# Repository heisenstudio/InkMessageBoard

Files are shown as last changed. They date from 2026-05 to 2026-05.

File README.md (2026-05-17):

# InkMessageBoard 墨水屏留言板

中文 | [English](README.en.md)

> 这是一个个人学习和交流用的开源原型项目，欢迎参考、复现和继续改进。它不是成熟商业产品，不保证商用稳定性，也不建议未经验证直接量产。

InkMessageBoard 是一个基于 **ESP32-S3、墨水屏、MQTT 和 Android App** 的留言板原型项目。核心流程是：Android App 输入留言，通过 MQTT 发布消息；ESP32-S3 连接 Wi-Fi 和 MQTT Broker，收到留言后刷新墨水屏；设备也可以上报在线状态、电量、RSSI、固件版本和留言处理状态。

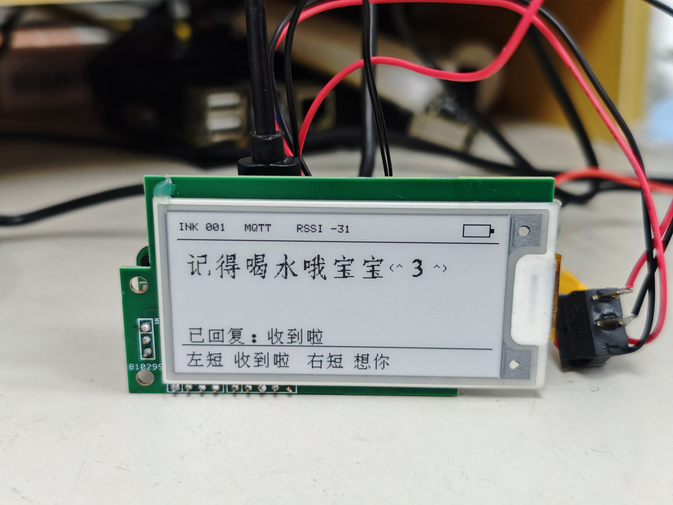
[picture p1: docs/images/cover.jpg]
设备实物


## 项目图片

| 设备正面 | 设备侧面 |
| --- | --- |
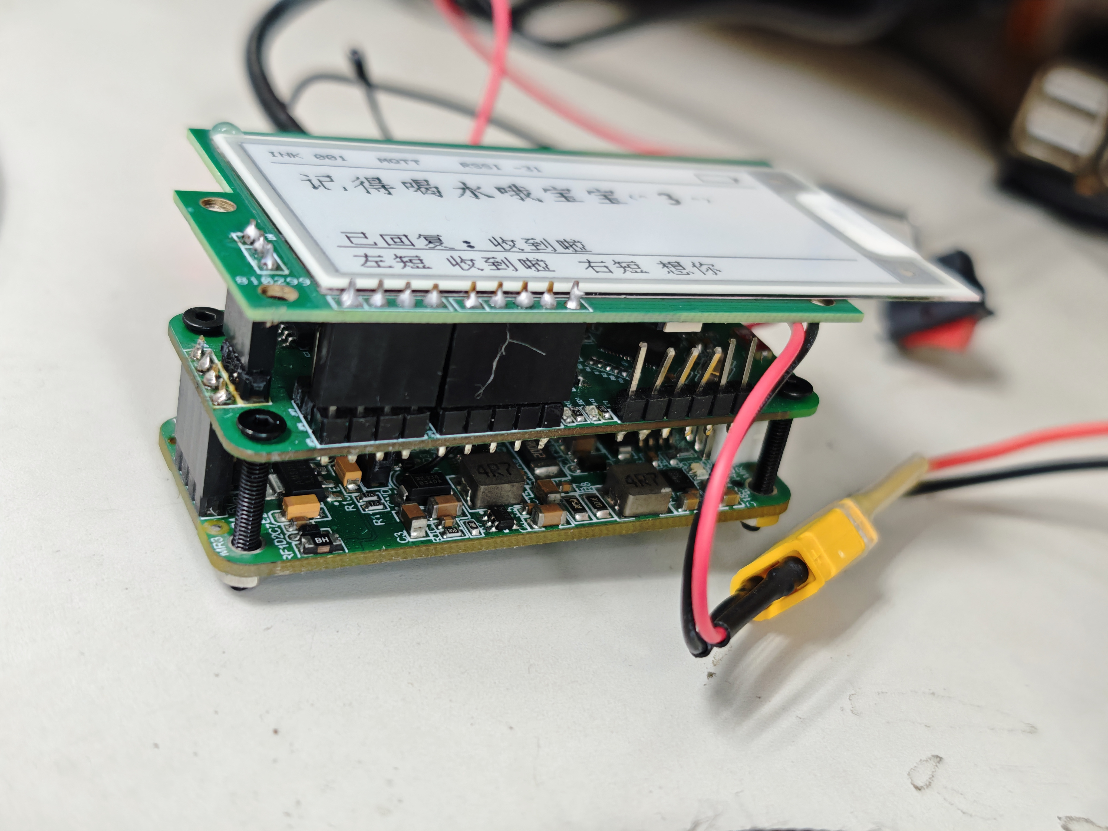
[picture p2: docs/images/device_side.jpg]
设备侧面
| 设备正面 |  |

| App 界面 | 系统架构 |
| --- | --- |
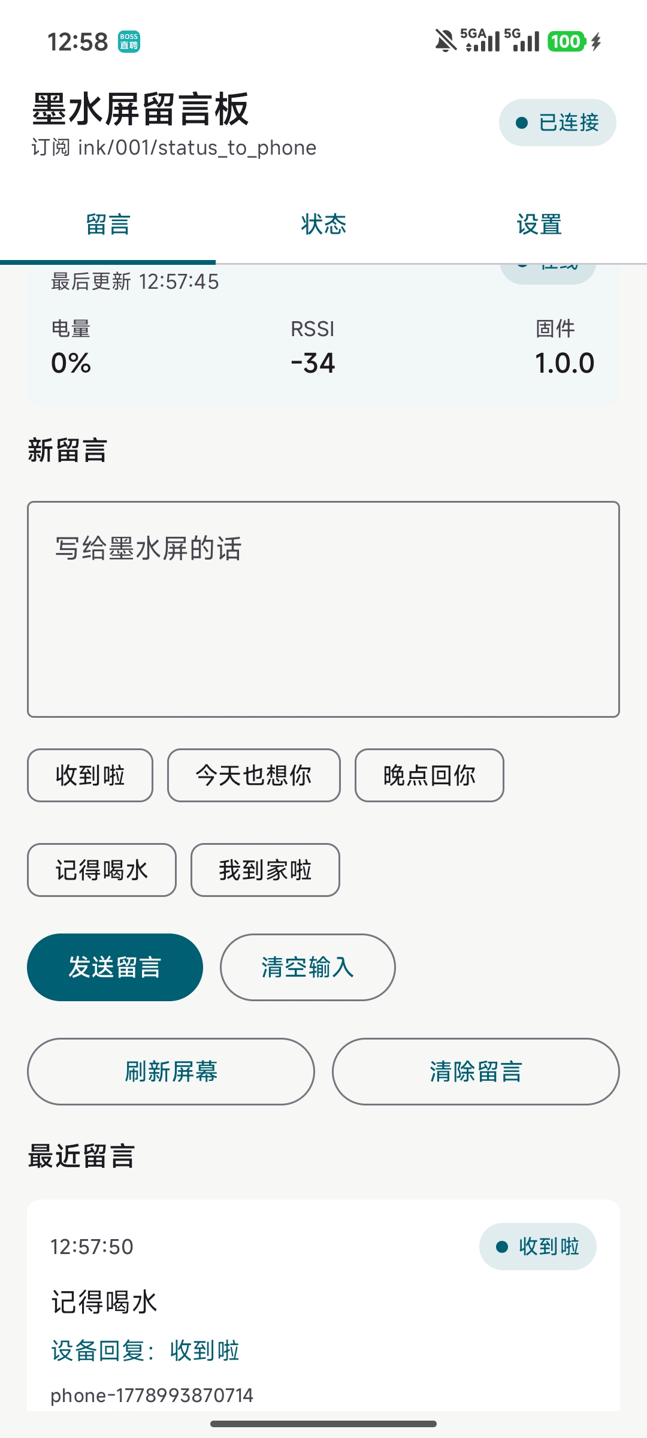
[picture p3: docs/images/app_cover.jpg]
App 界面
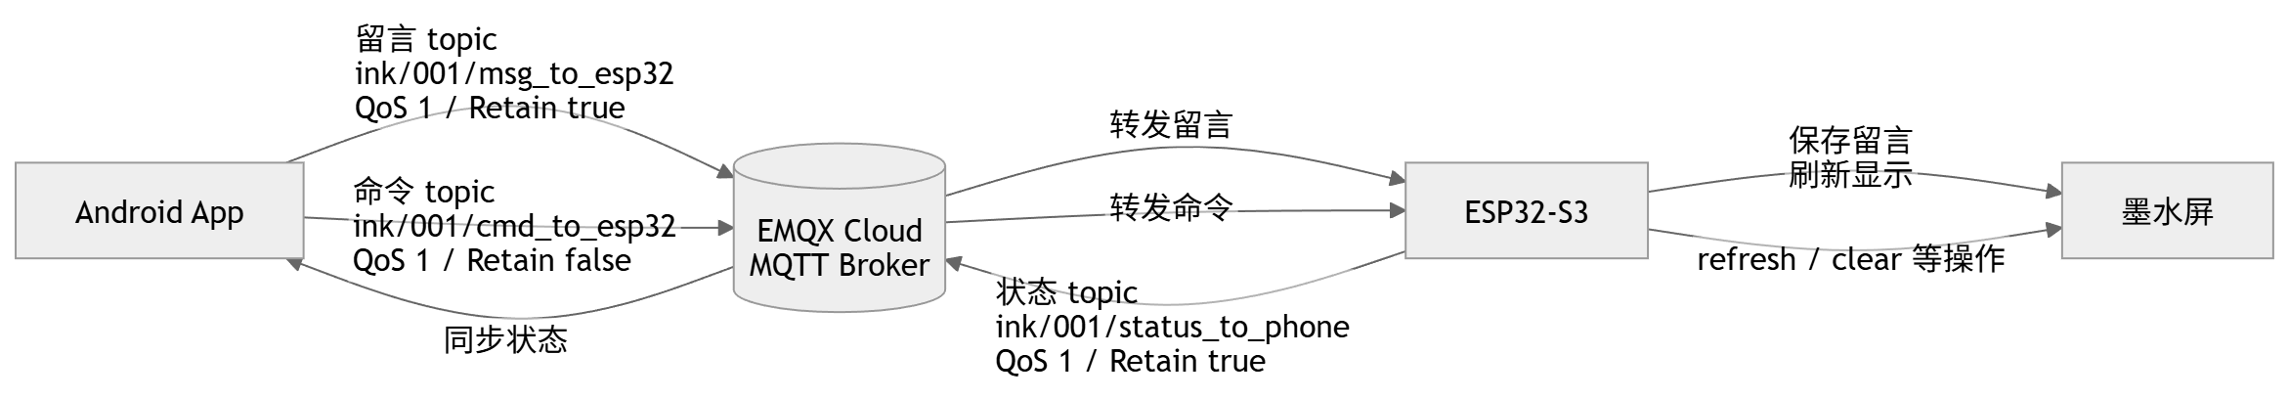
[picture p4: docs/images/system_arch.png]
系统架构
|  |  |

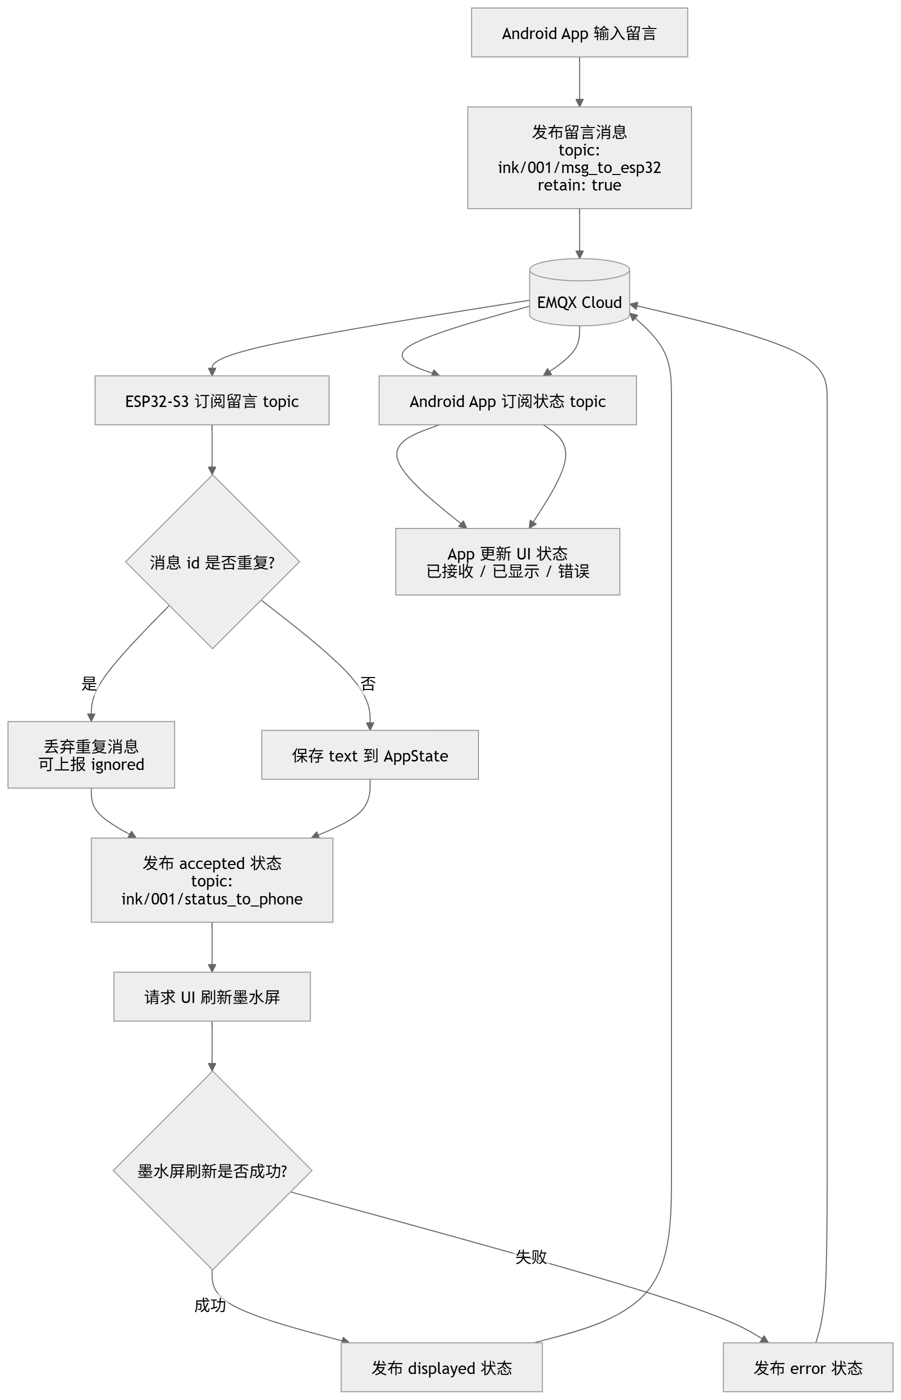
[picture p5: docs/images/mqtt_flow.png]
留言发送与状态回执流程


## 已跑通的流程

1. Android App 输入留言。
2. App 通过 MQTT 发布消息。
3. ESP32-S3 连接 Wi-Fi 和 MQTT Broker。
4. ESP32-S3 订阅留言 Topic 和命令 Topic。
5. ESP32-S3 收到留言后刷新墨水屏。
6. 设备可以通过触摸按键回传简单状态。
7. App 可以看到设备上报的在线、电量、RSSI、固件版本等信息。

MQTT 测试时使用过 EMQX Cloud。仓库里不包含真实 Broker 地址、用户名和密码，复现时请填写自己的测试账号。

## 项目定位

这个仓库主要是学习记录和交流资料，不是成熟产品。它适合用来学习：

- ESP32-S3 + Arduino/PlatformIO 工程组织
- Wi-Fi、MQTT、TLS 连接和重连
- 墨水屏刷新和中文点阵字体显示
- Android Compose 简单界面
- Android 与嵌入式设备之间的 MQTT 交互
- 原理图、PCB、Gerber、BOM 等开源硬件资料整理

目前仍然不完善：

- 没有做成稳定商品
- 没有完整安全设计
- 没有完整生产测试流程
- Android 和固件代码还有继续整理空间
- 文档中的参数、调试经验和复现细节仍可继续补充

## 仓库结构

```text
InkMessageBoard/
├── android/              # Android App 工程
├── firmware/esp32/       # ESP32-S3 PlatformIO 固件工程
├── hardware/             # 三块板子的源工程、原理图、PCB 图、Gerber、BOM
├── docs/                 # 构建、协议、软硬件说明
└── media/                # 视频脚本和演示素材
```

## 文档入口

- [软件介绍](docs/software_overview.md)
- [硬件介绍](docs/hardware_overview.md)
- [MQTT 协议](docs/mqtt_protocol.md)
- [ESP32 固件编译](docs/build_firmware.md)
- [Android App 编译](docs/build_android.md)
- [硬件连接](docs/hardware_connection.md)
- [已知问题](docs/known_issues.md)

## 开源内容

当前仓库包含：

- ESP32-S3 固件源码和 PlatformIO 配置
- Android App 源码和 Gradle 配置
- 三块板子的硬件源工程
- 原理图 PDF
- PCB 正反面图片
- Gerber 压缩包
- BOM 和贴片坐标文件
- 设备照片、流程图和 App 展示图

## 隐私和凭据

公开发布前已经处理：

- 删除 Android `local.properties`
- 删除 Android/ESP32 构建缓存
- 删除固件工程里嵌套的 `.git`
- 移除真实 EMQX Cloud Host、用户名和密码
- 示例配置使用占位符

你自己 fork 或二次发布前，也请再检查一次 Wi-Fi、MQTT、截图、串口日志和图片背景里是否有私人信息。

## 许可证

当前仓库的软件代码、文档、图片资料和硬件设计文件默认都使用 MIT License，见 [LICENSE](LICENSE)。

硬件部分同样按 MIT License 开放，方便大家学习、修改、制造和继续完善。打板和使用前请自行核对原理图、PCB、BOM、Gerber 和装配方式。

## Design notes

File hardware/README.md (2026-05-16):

# Hardware

这里放的是 InkMessageBoard 的硬件资料。当前是学习原型资料，不是成熟量产包。

硬件设计文件默认使用 MIT License，和仓库根目录 [LICENSE](../LICENSE) 保持一致。你可以学习、修改、制造和分发，但打板和使用前需要自行核对设计文件。

## 板子

| 板子 | 源工程 | 说明 |
| --- | --- | --- |
| ESP32-S3 主控板 | `source/altium/esp32_s3_board/` | AD 工程 |
| 电源板 | `source/altium/power_board/` | AD 工程 |
| 2.66 寸墨水屏板 | `source/lceda/ink_board/` | 嘉立创 EDA 工程 |

## 目录

```text
hardware/
├── source/       # 可编辑源工程
├── schematic/    # 原理图 PDF
├── pcb/          # PCB 正反面图片
├── gerber/       # Gerber 压缩包
├── bom/          # BOM 表
└── production/   # 贴片坐标和装配说明
```

## 开源硬件说明

硬件开源不只是放几张图。这个目录里保留了可编辑源工程，也另外导出了原理图、PCB 图片、Gerber、BOM 和贴片坐标，方便别人学习、检查或继续修改。

发布或打板前建议再做一次人工核对：

- 原理图是否对应当前固件引脚
- PCB 是否是实际测试过的版本
- BOM 封装和值是否正确
- Gerber 和贴片坐标是否来自同一版工程
- 电源输入、屏幕排线方向、触摸按键是否和实物一致

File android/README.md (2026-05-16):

# Android App

这里是 InkMessageBoard 的 Android App 工程。

这个 App 是学习原型，不是完整产品。它主要用来测试 Android 端通过 MQTT 给 ESP32-S3 发送留言，并查看设备回传状态。

## 功能

- 填写 MQTT host、端口、用户名、密码和设备 ID
- 连接 MQTT Broker
- 发送留言到 ESP32-S3
- 发送刷新/清除命令
- 显示设备状态 topic 和事件日志

## 构建

见 [../docs/build_android.md](../docs/build_android.md)。

## 隐私

仓库里不应该包含真实 MQTT 密码、签名文件或 `local.properties`。

当前默认 MQTT 配置是占位符。请在本地填写自己的 EMQX Cloud 或其他 MQTT Broker 信息。

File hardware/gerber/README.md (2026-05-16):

# Gerber

这里放 PCB 生产文件压缩包。

当前包括：

- `esp32_s3_board_gerber.zip`
- `power_board_gerber.zip`

`ink_board` 当前只整理了嘉立创 EDA 源工程和原理图 PDF，如需打板，请从源工程重新导出对应生产文件。

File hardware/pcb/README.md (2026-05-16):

# PCB Images

这里放 PCB 正反面预览图。

当前包括：

- `esp32_s3_board_front.png`
- `esp32_s3_board_back.png`
- `power_board_front.png`
- `power_board_back.png`
- `ink_board_front.png`
- `ink_board_back.png`

图片方便在 GitHub 上快速查看，真正可修改的源工程在 `hardware/source/`。

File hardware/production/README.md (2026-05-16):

# Production Files

这里放生产和装配相关文件。

当前包括：

- `esp32_s3_board_PickAndPlace.csv`
- `esp32_s3_board_PickAndPlace.txt`
- `power_board_PickAndPlace.csv`
- `assembly_notes.md`

这些文件适合学习和打样参考。正式下单前请重新从源工程导出并核对。

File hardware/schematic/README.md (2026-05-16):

# Schematic

这里放原理图导出文件。

当前包括：

- `esp32_s3_board.pdf`
- `power_board.pdf`
- `ink_board.pdf`

发布前建议继续核对：这些 PDF 是否和 `hardware/source/` 中的源工程、`hardware/gerber/` 中的生产文件对应同一版本。

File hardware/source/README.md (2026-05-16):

# Hardware Source Files

这里放可编辑的硬件源工程。

## 当前内容

```text
source/
├── altium/
│   ├── esp32_s3_board/
│   └── power_board/
└── lceda/
    └── ink_board/
```

`altium/` 下面是 AD 工程，`lceda/` 下面是嘉立创 EDA 工程。

这些源文件比导出的图片/Gerber 更重要，因为别人可以基于它们学习、修改、重新导出生产文件。

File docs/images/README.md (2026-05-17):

# Image Assets

这里放 README 和文档会引用的图片。

当前包括：

| File | Content |
| --- | --- |
| `cover.jpg` | 项目封面图 |
| `device_front.jpg` | 设备实物正面 |
| `device_side.jpg` | 设备侧面 |
| `app_cover.jpg` | Android App 展示图 |
| `pcb_front.png` | ESP32-S3 主控板正面图 |
| `pcb_back.png` | ESP32-S3 主控板背面图 |
| `system_arch.png` | 三条 Topic 总体数据流 |
| `mqtt_flow.png` | 留言发送与状态回执流程 |

没有放入显示真实 EMQX Cloud host 的状态页截图。公开截图前请检查是否包含 broker 地址、账号、密码、手机号、定位等私人信息。

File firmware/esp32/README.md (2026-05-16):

# ESP32 Firmware

This is the ESP32-S3 firmware for the InkMessageBoard prototype.

The firmware connects to Wi-Fi, connects to an MQTT broker, receives messages from the Android app, and refreshes the e-paper display. It is shared as a learning/reference project, not as a polished production firmware.

## Main Features

- Wi-Fi connection and retry
- MQTT over TLS, tested with free EMQX Cloud
- Message, command, and status topics
- E-paper UI pages for boot, offline, idle, message, and reply state
- Basic battery/status reporting
- GB2312 font data for Chinese text rendering

## Build

Install PlatformIO, then build from this directory:

```bash
pio run
```

Flash:

```bash
pio run --target upload
```

Upload filesystem data if needed:

```bash
pio run --target uploadfs
```

## Configuration

Edit `src/config/AppConfig.h` before building.

The values in that file are placeholders. Replace them with your own Wi-Fi and MQTT information. Do not publish real Wi-Fi passwords, MQTT passwords, or private broker addresses.

## Dependencies

Third-party Arduino libraries are declared in `platformio.ini` through `lib_deps`. Build caches and downloaded libraries are intentionally not committed.

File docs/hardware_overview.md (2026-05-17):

# 硬件介绍

这个项目的硬件部分目前包含三块板子的资料。它们都是学习和原型验证用途，不建议直接当成成熟量产资料使用。

硬件设计文件同样使用 MIT License 开放。你可以学习、修改、制造和分发，但实际打板、装配、供电和使用风险需要自行确认。

## 板子列表

| 板子 | 工程类型 | 说明 |
| --- | --- | --- |
| ESP32-S3 主控板 | Altium Designer | 主控、Wi-Fi/MQTT、墨水屏控制、触摸输入等 |
| 电源板 | Altium Designer | 供电相关电路 |
| 2.66 寸墨水屏板 | 嘉立创 EDA | 墨水屏连接/转接相关电路 |

## 开源资料位置

```text
hardware/
├── source/
│   ├── altium/
│   │   ├── esp32_s3_board/
│   │   └── power_board/
│   └── lceda/
│       └── ink_board/
├── schematic/
├── pcb/
├── gerber/
├── bom/
└── production/
```

## 已整理的文件

- AD 源工程：`hardware/source/altium/`
- 嘉立创 EDA 工程：`hardware/source/lceda/`
- 原理图 PDF：`hardware/schematic/`
- PCB 正反面图：`hardware/pcb/`
- Gerber 压缩包：`hardware/gerber/`
- BOM：`hardware/bom/`
- 贴片坐标：`hardware/production/`

## 实物和 PCB 图片

设备正面

设备侧面

## PCB 图片

### ESP32-S3 主控板

| 正面 | 背面 |
| --- | --- |
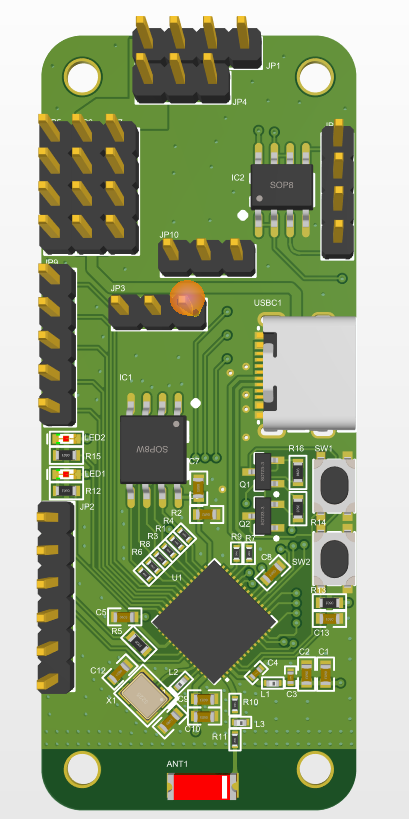
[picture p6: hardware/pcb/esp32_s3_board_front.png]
ESP32-S3 主控板正面
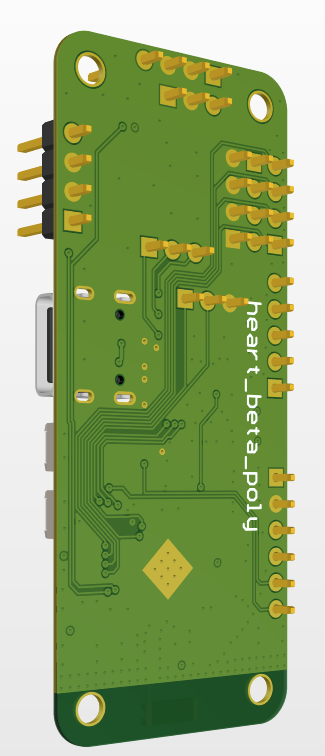
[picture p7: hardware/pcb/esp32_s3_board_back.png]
ESP32-S3 主控板背面
|  |  |

### 电源板

| 正面 | 背面 |
| --- | --- |
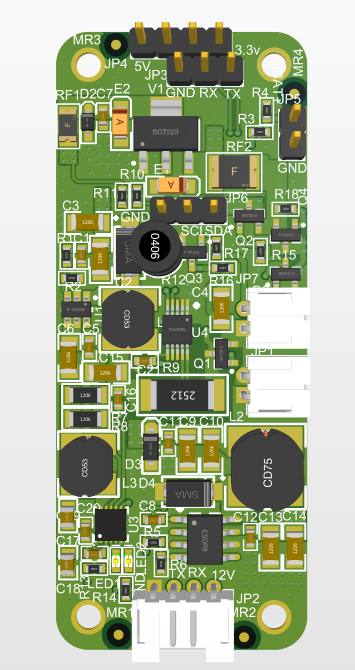
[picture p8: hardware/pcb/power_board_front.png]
电源板正面
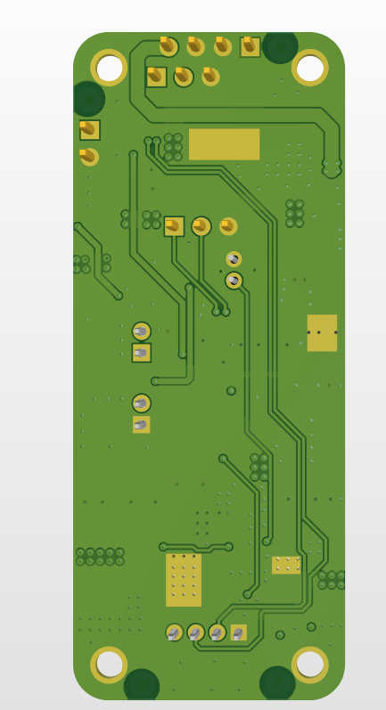
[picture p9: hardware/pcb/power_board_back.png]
电源板背面
|  |  |

### 2.66 寸墨水屏板

| 正面 | 背面 |
| --- | --- |
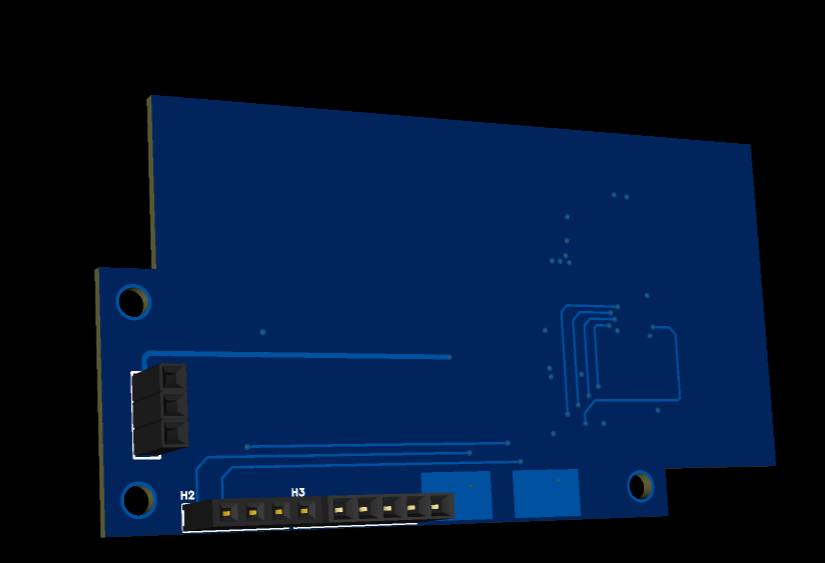
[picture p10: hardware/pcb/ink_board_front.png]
墨水屏板正面
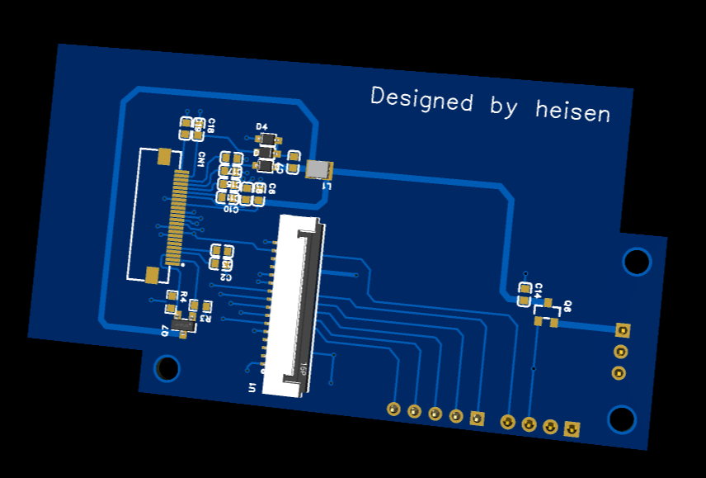
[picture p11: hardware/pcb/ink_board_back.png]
墨水屏板背面
|  |  |

## 注意事项

- 硬件源文件是开源硬件最重要的部分，图片和 Gerber 不能完全替代源工程。
- 发布或打板前，请重新检查原理图、封装、BOM 和 Gerber 是否对应同一个版本。
- 如果你要基于这个项目改板，建议先从原理图和实际焊接照片一起核对。
- 电源、电池、充电、墨水屏排线方向这些地方需要特别小心。

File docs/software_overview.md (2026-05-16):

# 软件介绍

这个项目的软件部分分成两块：

- ESP32-S3 固件：负责联网、接收 MQTT 消息、驱动墨水屏、上报状态。
- Android App：负责输入留言、连接 MQTT Broker、发布消息和命令、显示设备状态。

整体上它是一个学习用的 IoT 原型，不是完整产品级架构。代码能作为参考，但仍然有很多地方可以继续整理。

## 通信流程

三条 Topic 总体数据流

留言发送与状态回执流程

```text
Android App
   |
   | MQTT over TLS
   v
EMQX Cloud / MQTT Broker
   |
   | MQTT over TLS
   v
ESP32-S3
   |
   v
E-paper display
```

测试时使用过免费的 EMQX Cloud。仓库里不包含真实 host、用户名和密码，请在本地配置自己的 MQTT 信息。

## ESP32-S3 固件

固件位置：

```text
firmware/esp32/
```

主要模块：

| 模块 | 作用 |
| --- | --- |
| `main.cpp` | 主循环、消息解析、屏幕刷新调度 |
| `service/WifiService.*` | Wi-Fi 连接 |
| `service/MqttService.*` | MQTT TLS 连接、订阅、发布 |
| `service/KeyService.*` | 左右触摸按键 |
| `service/BatteryService.*` | 电量采样和状态 |
| `bsp/BspEpaper.*` | 墨水屏底层封装 |
| `bsp/BspBattery.*` | INA226 电量检测 |
| `data/fonts/` | HZK 点阵字体和 Unicode/GB2312 映射 |

固件当前使用 PlatformIO + Arduino framework。第三方库通过 `platformio.ini` 的 `lib_deps` 下载，不提交 `.pio` 缓存。

## Android App

App 位置：

```text
android/
```

主要模块：

| 模块 | 作用 |
| --- | --- |
| `MainActivity.kt` | Compose 页面和交互 |
| `GuestbookController.kt` | App 状态、MQTT 配置、消息发送 |
| `mqtt/SimpleMqttClient.kt` | 一个简单的 MQTT over TLS 客户端实现 |

App 目前比较直接：启动后使用配置连接 MQTT，留言页发布消息，状态页显示 topic 和设备回传事件，设置页可以修改 broker、账号、设备 ID 等信息。

## 还可以完善的方向

- 把 MQTT 配置做成更清晰的首次启动引导。
- 增加连接失败原因提示。
- App 端可以增加本地配置导入/导出。
- 固件可以增加更稳健的断线重连策略。
- 固件中文字符串和字体资源还可以继续整理。
- 可以把系统架构图和 MQTT 流程图补成图片。

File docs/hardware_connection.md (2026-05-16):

# Hardware Connection

这里先按当前固件里的引脚定义整理，后续如果硬件版本变化，需要同步检查原理图和代码。

## 主要硬件

| 部分 | 说明 |
| --- | --- |
| MCU | ESP32-S3 |
| 显示 | 2.66 寸黑白墨水屏，固件使用 `GxEPD2_260` |
| 电量检测 | INA226 |
| 输入 | 左右触摸按键 |
| 通信 | Wi-Fi + MQTT over TLS |

## 墨水屏 SPI

| 功能 | ESP32-S3 GPIO | 固件宏 |
| --- | --- | --- |
| SCK | GPIO33 | `BSP_EPAPER_SPI_SCK_PIN` |
| MOSI | GPIO34 | `BSP_EPAPER_SPI_MOSI_PIN` |
| MISO | 未使用 | `BSP_EPAPER_SPI_MISO_PIN = -1` |
| CS | GPIO47 | `BSP_EPAPER_CS_PIN` |
| DC | GPIO48 | `BSP_EPAPER_DC_PIN` |
| RST | GPIO35 | `BSP_EPAPER_RST_PIN` |
| BUSY | GPIO8 | `BSP_EPAPER_BUSY_PIN` |
| Power Enable | GPIO9 | `BSP_EPAPER_POWER_EN_PIN` |

## INA226 电量检测

| 功能 | ESP32-S3 GPIO | 固件宏 |
| --- | --- | --- |
| SDA | GPIO12 | `BSP_BATTERY_SDA_PIN` |
| SCL | GPIO13 | `BSP_BATTERY_SCL_PIN` |
| I2C 地址 | `0x40` | `BSP_BATTERY_I2C_ADDRESS` |

## 触摸按键

| 功能 | ESP32-S3 GPIO | 固件宏 |
| --- | --- | --- |
| 左触摸 | GPIO11 | `KEYSERVICE_LEFT_TOUCH_PIN` |
| 右触摸 | GPIO10 | `KEYSERVICE_RIGHT_TOUCH_PIN` |

## 注意

- 这些引脚来自当前固件，开源发布前最好再和 AD/嘉立创 EDA 原理图逐项核对。
- 墨水屏排线方向、电源使能、电池检测电阻值都建议在装配说明里继续补图。
- 如果你改板，请同步改 `firmware/esp32/src/bsp/` 和 `firmware/esp32/src/service/` 里的默认宏。

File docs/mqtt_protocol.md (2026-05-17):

# MQTT Protocol

这个项目目前使用 MQTT 做 App 和 ESP32-S3 之间的通信。测试时使用过免费的 EMQX Cloud，端口为 `8883`，连接走 TLS。

仓库不提供真实 broker 地址、用户名和密码。请在本地填自己的配置。

## Topics

默认设备 ID 是 `001`。

| 方向 | Topic | 作用 |
| --- | --- | --- |
| App -> ESP32 | `ink/001/msg_to_esp32` | 发送留言 |
| App -> ESP32 | `ink/001/cmd_to_esp32` | 发送控制命令 |
| ESP32 -> App | `ink/001/status_to_phone` | 上报设备状态、留言状态和按键回复 |

## 留言消息

App 发布到 `ink/001/msg_to_esp32`：

```json
{
  "id": "phone-1778844537408",
  "type": "guestbook",
  "text": "请查看设备状态",
  "ts": 1778844537
}
```

字段：

| 字段 | 类型 | 必填 | 说明 |
| --- | --- | --- | --- |
| `id` | string | 是 | 消息 ID，用于去重和状态回传 |
| `type` | string | 否 | 当前 App 使用 `guestbook` |
| `text` | string | 是 | 显示到墨水屏上的文字 |
| `ts` | number | 否 | App 侧生成的 Unix 时间戳 |

## 控制命令

App 发布到 `ink/001/cmd_to_esp32`：

```json
{
  "id": "cmd-1778844537408",
  "cmd": "refresh"
}
```

当前命令：

| 命令 | 说明 |
| --- | --- |
| `refresh` | 强制刷新屏幕 |
| `clear` | 清除当前留言并刷新 |

## 设备状态

ESP32 发布到 `ink/001/status_to_phone`：

```json
{
  "online": true,
  "battery": 80,
  "rssi": -38,
  "fw": "1.0.0"
}
```

## 留言状态回传

ESP32 收到、显示或按键回复后，也发布到 `ink/001/status_to_phone`：

```json
{
  "msg_id": "phone-1778844537408",
  "state": "displayed"
}
```

带回复文本的例子：

```json
{
  "msg_id": "phone-1778844537408",
  "state": "seen",
  "text": "已收到"
}
```

常见 `state`：

| state | 说明 |
| --- | --- |
| `accepted` | ESP32 已接收消息 |
| `displayed` | ESP32 已刷新到墨水屏 |
| `seen` | 左短按回复，表示已收到 |
| `confirm` | 右短按回复，表示需要确认 |
| `later` | 左长按回复，表示稍后处理 |
| `done` | 右长按回复，表示已处理 |

## 注意

- 免费 MQTT Broker 适合学习测试，不建议传隐私内容。
- 真实 host、用户名、密码不要提交到 GitHub。
- 当前固件使用 `setInsecure()`，也就是没有校验证书链，后续可以继续完善 TLS 证书校验。

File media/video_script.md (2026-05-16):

# Demo Video Script

## Title

ESP32 墨水屏 MQTT 留言板原型

## 30-60 Second Flow

1. Show the assembled device.
2. Show the Android app input screen.
3. Enter a short message.
4. Tap send.
5. Show MQTT message being delivered, if you want to include a debug shot.
6. Show the e-paper display refreshing.
7. End with the GitHub repository structure: firmware, android, hardware, docs.

## Key Message

这是一个 ESP32 + 墨水屏 + MQTT + Android App 的留言板原型项目。核心功能已跑通，适合作为嵌入式 IoT 学习和作品集参考。

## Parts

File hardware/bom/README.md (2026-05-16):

# BOM

这里放物料清单。

当前包括：

- `esp32_s3_board_BOM.xlsx`
- `power_board_BOM.xlsx`

这些文件来自工程输出。发布或打样前建议人工核对型号、封装和值。

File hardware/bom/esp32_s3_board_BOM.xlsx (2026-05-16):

Comment | Description | Designator | Footprint | LibRef | Quantity
CrossAir CA-C03 | 2450±50MHz 4.3DBi 50欧 功率3W | ANT1 | crossair ca-co3 | CrossAir CA-C03 | 1
10uf | 贴片电容/MLCC电容 | C1 | C0603_L | C | 1
1uf | 贴片电容/MLCC电容 | C2, C6, C9, C13 | C0603_L | C | 4
100nf | 贴片电容/MLCC电容 | C3, C4 | C0402_L | C | 2
100nf | 贴片电容/MLCC电容 | C5, C7, C8 | C0603_L | C | 3
10nf | 贴片电容/MLCC电容 | C10 | C0603_L | C | 1
24pf | 贴片电容/MLCC电容 C1654 | C11, C12 | C0603_L | C | 2
W25Q64 | SPI Flash C83140 | IC1 | SOP8W_L | W25Q | 1
LM358 | 双路运放 | IC2 | SOP8_N | LM358 | 1
HDR-1X4 | 4P接插件 | JP1, JP5, JP6, JP7, JP8 | HDR2.54-LI-4P | Header 4 | 5
HDR-1X6 | 6P接插件 | JP2 | HDR2.54-LI-6P | Header 6 | 1
HDR-1X3 | 3P接插件 | JP3, JP4, JP10 | HDR2.54-LI-3P | Header 3 | 3
HDR-1X5 | 5P接插件 | JP9 | HDR2.54-LI-5P | Header 5 | 1
2nh | 贴片小功率电感 C18216 | L1 | L0402 | L | 1
24nh | 贴片小功率电感 C74301 | L2 | L0402 | L | 1
3nh | 贴片小功率电感 | L3 | L0402 | L | 1
红色 | 贴片LED | LED1, LED2 | LED0603_R | LED | 2
SS8050 | 高频放大-NPN型 | Q1, Q2 | SOT23-3N | 8050-SMD | 2
0R | 贴片电阻 | R1, R2, R3, R4, R6, R7, R8, R9, R10, R11 | R0402_L | R | 10
499R | 贴片电阻 | R5 | R0603_L | R | 1
470R | 贴片电阻 | R12, R15 | R0603_L | R | 2
10K | 贴片电阻 | R13, R14, R16 | R0603_L | R | 3
3*4*2.5 | 贴片4脚轻触开关 C2690012 | SW1, SW2 | SW-SMD-4.2x3.2_4P | SW SMD-3*4*2.5 | 2
ESP32-S3 | 2.4 GHz Wi-Fi + 低功耗蓝牙 SoC | U1 | QFN56 7x7 | ESP32-S3 | 1
TYPE-C 2.0 -16P | USB2.0_Type-C_16Pin母座 | USBC1 | USB-C-SMD_16P | USB2.0_Type-C_16Pin | 1
40Mhz | 4脚无源晶振(谐振器）C5203551 | X1 | XTAL-3225-4P | XTAL-4P | 1

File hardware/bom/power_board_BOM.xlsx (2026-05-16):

Comment | Description | Designator | Footprint | LibRef | Quantity | jlc_id
100nf | 贴片电容/MLCC电容 | C1, C5, C11, C12, C16, C17, C20, C21 | C0603_L | C | 8
100uf/6.3V | 贴片电容/MLCC电容, 贴片电容/MLCC电容 C15008 | C2, C3, C4, C9, C10, C15 | C1206_L | C | 6 | C15008, [NoParam], C45783
22uf/25V | 贴片电容/MLCC电容, 贴片电容/MLCC电容 C12891 | C6, C13, C14 | C1206_L | C | 3
4.7uf | 贴片电容/MLCC电容 | C7 | C0603_M | C | 1
10nf | 贴片电容/MLCC电容 | C8 | C0603_L | C | 1
22uf/25v | 贴片电容/MLCC电容 | C18, C19 | C0805_L | C | 2 | C45783
B340A-13-F | 肖特基二极管 C85098 | D1, D4 | SMA | B340A-13-F | 2
UDD32C03L01 | TVS通用 C78439 | D2 | SOD-323 | TVS | 1
SMF5.0A | TVS通用 | D3 | SOD-123 | TVS | 1
10uF/10V | 贴片钽电容 C7171 | E1 | C_3216 | CT | 1
22uF/10V | 贴片钽电容 C11366 | E2 | C_3216 | CT | 1
HDR-1X2 | 2P接插件 | JP1, JP7 | PH2.0-W-2P | Header 2 | 2
HDR-1X4 | 4P接插件 | JP2 | PH2.0-W-4P | Header 4 | 1
HDR-1X3 | 3P接插件 | JP3, JP6 | HDR2.54-LI-3P | Header 3 | 2
HDR-1X4 | 4P接插件 | JP4 | HDR2.54-LI-4P | Header 4 | 1
HDR-1X2 | 2P接插件 | JP5 | HDR2.54-LI-2P | Header 2 | 1
4.7uH | CD系列贴片线绕功率电感 | L1, L3 | CD53 | L-SMD | 2 | C177246
15uH | CD系列贴片线绕功率电感 | L2 | CD75 | L-SMD | 1 | C177243
红色 | 贴片LED | LED1 | LED0603_Y | LED | 1
绿色 | 贴片LED | LED2 | LED0603_Y | LED | 1
MARK1.6 | 光学定位点 | MR1, MR2, MR3, MR4 | Mark 1 | MARK | 4
AO3401 | P沟道 30V/4.2A | Q1, Q2, Q4 | SOT23-3N | AO3401 | 3 | C347476
S8050 | NPN三极管 | Q3 | SOT23-3M | BCP68 | 1
AO3400 | N沟道 30V/4.2A | Q5 | SOT23-3N | AO3400 | 1 | C20917
110K | 贴片电阻 | R1 | R0603_L | R | 1
15K | 贴片电阻 | R2 | R0603_L | R | 1
10K/0.1% | 贴片电阻 | R3, R4 | R0603_L | R | 2
10k | 贴片电阻 | R5, R17 | R0603_L | R | 2
3.24k | 贴片电阻 | R6 | R0603_L | R | 1
0.05R | 贴片电阻 | R7 | R1206_L | R | 1 | C127691
0.1R | 贴片电阻 | R8 | R1206_L | R | 1 | C25334
0.002R | 贴片电阻 | R9 | R2512_M | R | 1 | C2994640
4.7K | 贴片电阻 | R10, R11 | R0603_L | R | 2
471K | 热敏电阻 | R12 | PK0406 | RT | 1
1K | 贴片电阻 | R13, R14 | R0603_L | R | 2
330K | 贴片电阻 | R15, R18 | R0603_L | R | 2
40K | 贴片电阻 | R16 | R0603_L | R | 1
BSMD1206-100-24V | PPTC自恢复保险丝 C910830 | RF1 | F1206 | FUSE-PPTC | 1
SMD1812-300C-16V | PPTC自恢复保险丝 | RF2 | F1812 | FUSE-PPTC | 1 | C2760295
MT3608L | Boost升压DC-DC芯片 2-28V | U1 | SOT23-6M | MT3608L | 1
TPS5430DDAR | 5.5v到36v转1.3v到32v | U2 | SOIC-8_EP | TPS5430DDAR | 1
SLM6305 | 1锂电池充电ic 2.5a 4.2v 4V~26V输入 | U3 | DFN10-L3.0-W3.0-P0.5_EP | SLM6305 | 1 | C711584
INA226AIDGSR | 双向电流/功率监视器芯片 | U4 | MSOP10_N | INA226 | 1
AMS1117-3V3 | 三端稳压芯片 | V1 | SOT223_L | AMS1117 | 1

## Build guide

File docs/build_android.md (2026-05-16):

# Build Android App

Android 工程位于：

```text
android/
```

## 工具

- Android Studio
- 项目自带 Gradle Wrapper
- JDK 使用 Android Studio 自带版本即可

## 打开工程

用 Android Studio 打开 `android/` 目录。

不要提交 `local.properties`，里面会包含你本机 Android SDK 路径。

## MQTT 配置

App 默认值已经改成占位符。运行后可以在设置页填写自己的 MQTT 信息：

| 项目 | 说明 |
| --- | --- |
| MQTT Host | 你的 EMQX Cloud 或其他 broker 地址 |
| Port | TLS 通常为 `8883` |
| Username | 你的 MQTT 用户名 |
| Password | 你的 MQTT 密码 |
| Device ID | 默认 `001` |

## 编译

Windows：

```bat
cd android
gradlew.bat assembleDebug
```

macOS/Linux：

```bash
cd android
./gradlew assembleDebug
```

## 检查点

- App 能正常启动
- 设置页能填 MQTT 配置
- 状态页能显示连接日志
- 留言页能发布消息
- ESP32 能收到消息并刷新墨水屏

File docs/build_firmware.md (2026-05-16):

# Build Firmware

ESP32-S3 固件工程位于：

```text
firmware/esp32/
```

## 工具

- PlatformIO Core 或 VS Code PlatformIO 插件
- ESP32-S3 开发板串口驱动
- 可以访问 PlatformIO 依赖源的网络环境

## 配置

编辑：

```text
firmware/esp32/src/config/AppConfig.h
```

需要替换：

- `APP_WIFI_SSID`
- `APP_WIFI_PASSWORD`
- `APP_MQTT_HOST`
- `APP_MQTT_USERNAME`
- `APP_MQTT_PASSWORD`
- `APP_DEVICE_ID` 和相关 topic

不要把真实 Wi-Fi 密码、MQTT 密码提交到公开仓库。

## 编译

```bash
cd firmware/esp32
pio run
```

## 烧录

```bash
pio run --target upload
```

## 上传字体文件

固件使用 `data/fonts/` 下的 HZK 字体和映射文件，需要上传 LittleFS：

```bash
pio run --target uploadfs
```

## 串口监视

```bash
pio device monitor
```

## 检查点

- Wi-Fi 能连接
- MQTT 能连接到自己的 EMQX Cloud/Broker
- ESP32 订阅了留言和命令 topic
- App 能发出留言
- 墨水屏能刷新显示
- App 能收到 `accepted`、`displayed` 或按键回复状态

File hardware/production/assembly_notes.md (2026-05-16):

# Assembly Notes

这里先记录装配和上电检查清单。当前文档还不完整，后续可以继续补焊接照片、排线方向和关键测试点。

## Before Soldering

- 确认 PCB 版本。
- 确认 BOM 版本。
- 确认墨水屏排线方向。
- 确认电源输入电压。
- 确认贴片坐标和 Gerber 来自同一版工程。

## Notes

- ESP32-S3 主控板和电源板有 AD 工程和生产输出。
- 2.66 寸墨水屏板目前整理了嘉立创 EDA 源工程。
- 如果有手焊跳线、飞线或改版，请在这里补照片。

## Bring-Up Checklist

- [ ] 检查电源和地是否短路
- [ ] 限流上电
- [ ] 确认 3.3 V 电源
- [ ] 烧录 ESP32 固件
- [ ] 上传 LittleFS 字体文件
- [ ] 确认 Wi-Fi 连接
- [ ] 确认 MQTT 连接
- [ ] 发送 App 留言
- [ ] 墨水屏刷新显示

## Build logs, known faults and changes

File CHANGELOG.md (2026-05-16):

# Changelog

All notable changes to this project will be documented in this file.

## Unreleased

- Created open-source repository structure.
- Added ESP32-S3 firmware project.
- Added Android app project.
- Added hardware source files for ESP32-S3 board, power board, and 2.66-inch e-paper board.
- Added schematic PDFs, PCB images, Gerber archives, BOM exports, and pick-and-place files.
- Added real device photos and an App screenshot without broker credentials.
- Removed generated build caches and local machine files from firmware and Android projects.
- Replaced real MQTT connection values with public placeholders.
- Added software overview, hardware overview, build docs, MQTT protocol, and known issues.
- Added system/MQTT flow diagrams to README and docs.
- Clarified that hardware design files are also released under the MIT License.
- Added a clearer prototype disclaimer to README files.
- Added MIT License placeholder for the repository.

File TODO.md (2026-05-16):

# TODO

## Before First Public Release

- [x] Add real ESP32 firmware source code
- [x] Add real Android project source code
- [x] Add device photos
- [x] Add e-paper display photos
- [x] Add Android app screenshot without broker credentials
- [x] Add schematic PDFs
- [x] Add PCB front/back images
- [x] Add editable hardware source files
- [x] Add Gerber zip files for AD boards
- [x] Add BOM exports for AD boards
- [x] Add PickAndPlace exports for AD boards
- [x] Confirm final software license
- [x] Confirm final hardware license
- [ ] Test the documented firmware build steps from a clean checkout
- [ ] Test the documented Android build steps from a clean checkout
- [ ] Record a short demo video
- [x] Redraw system architecture diagram
- [x] Redraw MQTT flow diagram
- [ ] Add more assembly photos

## Firmware

- [x] Document supported ESP32 board model
- [x] Document e-paper display model and driver
- [x] Replace private Wi-Fi/MQTT values with placeholders
- [x] Add MQTT reconnect notes
- [x] Add display refresh/flicker limitations
- [ ] Consider moving local config into an ignored user config file
- [ ] Review Chinese string encoding in firmware UI

## Android

- [x] Document minimum Android version
- [x] Add MQTT broker configuration screen or example config
- [x] Add app screenshot
- [ ] Document tested Android Studio version
- [ ] Improve MQTT connection error messages

## Hardware

- [x] Add hardware source projects
- [x] Add schematic PDFs
- [x] Add PCB front/back images
- [x] Add Gerber/BOM/PnP exports for AD boards
- [ ] Verify schematic pin names match firmware pin definitions
- [ ] Verify BOM values and footprints
- [ ] Export manufacturing files from the final hardware revision
- [ ] Add assembly notes for screen cable direction and power input

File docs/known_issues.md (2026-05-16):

# Known Issues

这个项目目前就是学习原型，下面这些问题都可以继续改。

## 固件

- Wi-Fi/MQTT 重连逻辑还比较朴素。
- MQTT TLS 当前使用 `setInsecure()`，没有严格校验证书。
- 墨水屏刷新慢是正常现象，频繁全刷会闪烁。
- 中文字体和排版还可以继续整理。
- 固件里的部分 UI 文案/编码建议后续再统一检查。
- 电池百分比目前是按电压简单估算，不是精确电量计。

## Android

- MQTT 配置页比较基础。
- 连接失败时的错误提示还不够细。
- 默认包名还是示例风格，后续可以整理成更合适的命名。
- 目前没有做账号安全、证书管理、消息历史持久化等产品化能力。

## 硬件

- 三块板子的资料已经整理进仓库，但发布/打板前仍建议重新核对版本。
- BOM 和贴片坐标来自工程输出，最好再人工检查一遍。
- 装配说明还需要继续补照片，特别是排线方向和电源连接。
- 没有做完整的生产测试流程。

## 文档

- 构建步骤还需要从干净电脑完整跑一遍。
- 系统架构图和 MQTT 流程图还没有正式绘制。
- 视频演示素材可以继续补。

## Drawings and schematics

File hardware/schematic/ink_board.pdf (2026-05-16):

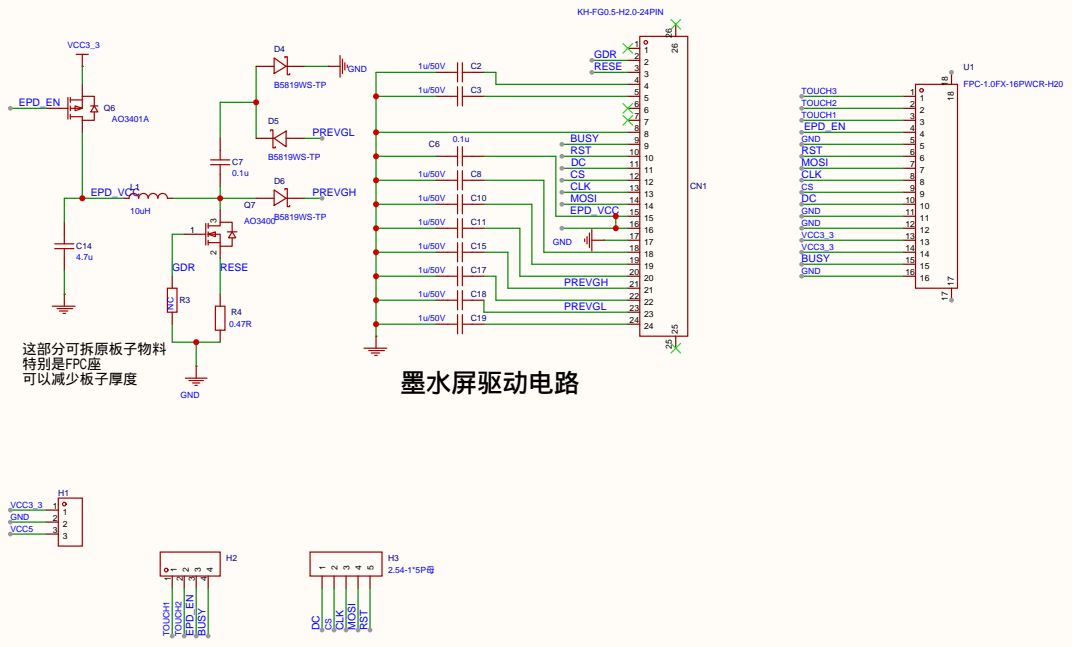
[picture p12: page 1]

原理图 | Schematic1 | 创建日期 | 2025-07-16

更新日期 | 2025-07-17

板子 | Board1 | 图页 | P1
绘制 | | 2.66board
审阅

V1.0 | A4 | 嘉立创EDA

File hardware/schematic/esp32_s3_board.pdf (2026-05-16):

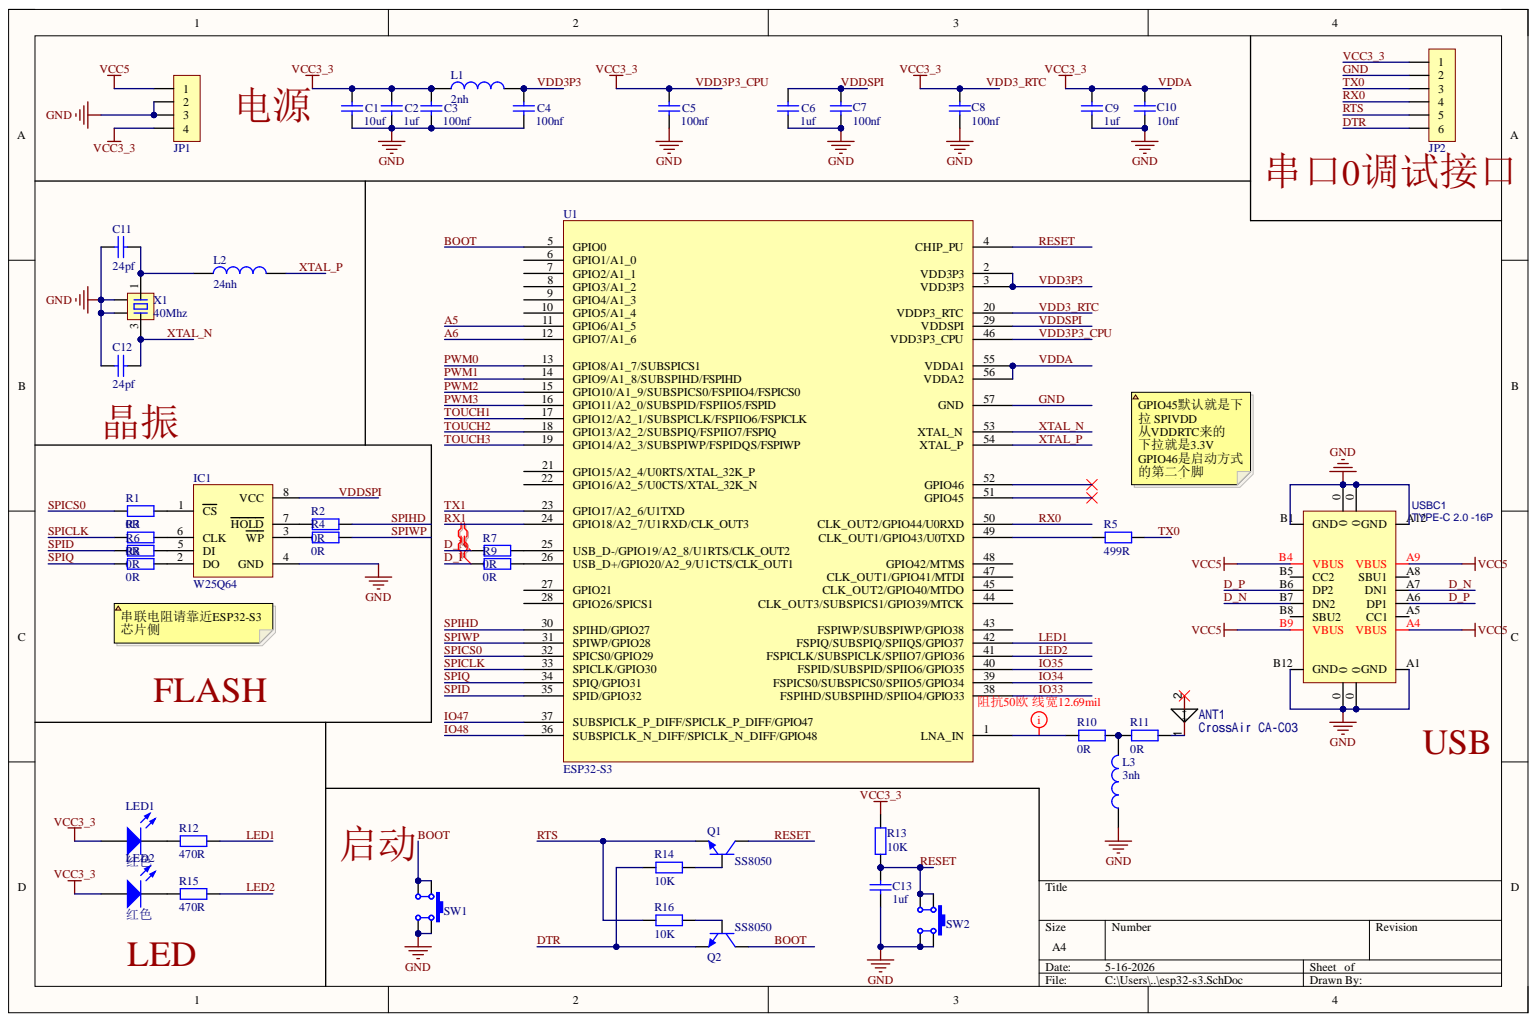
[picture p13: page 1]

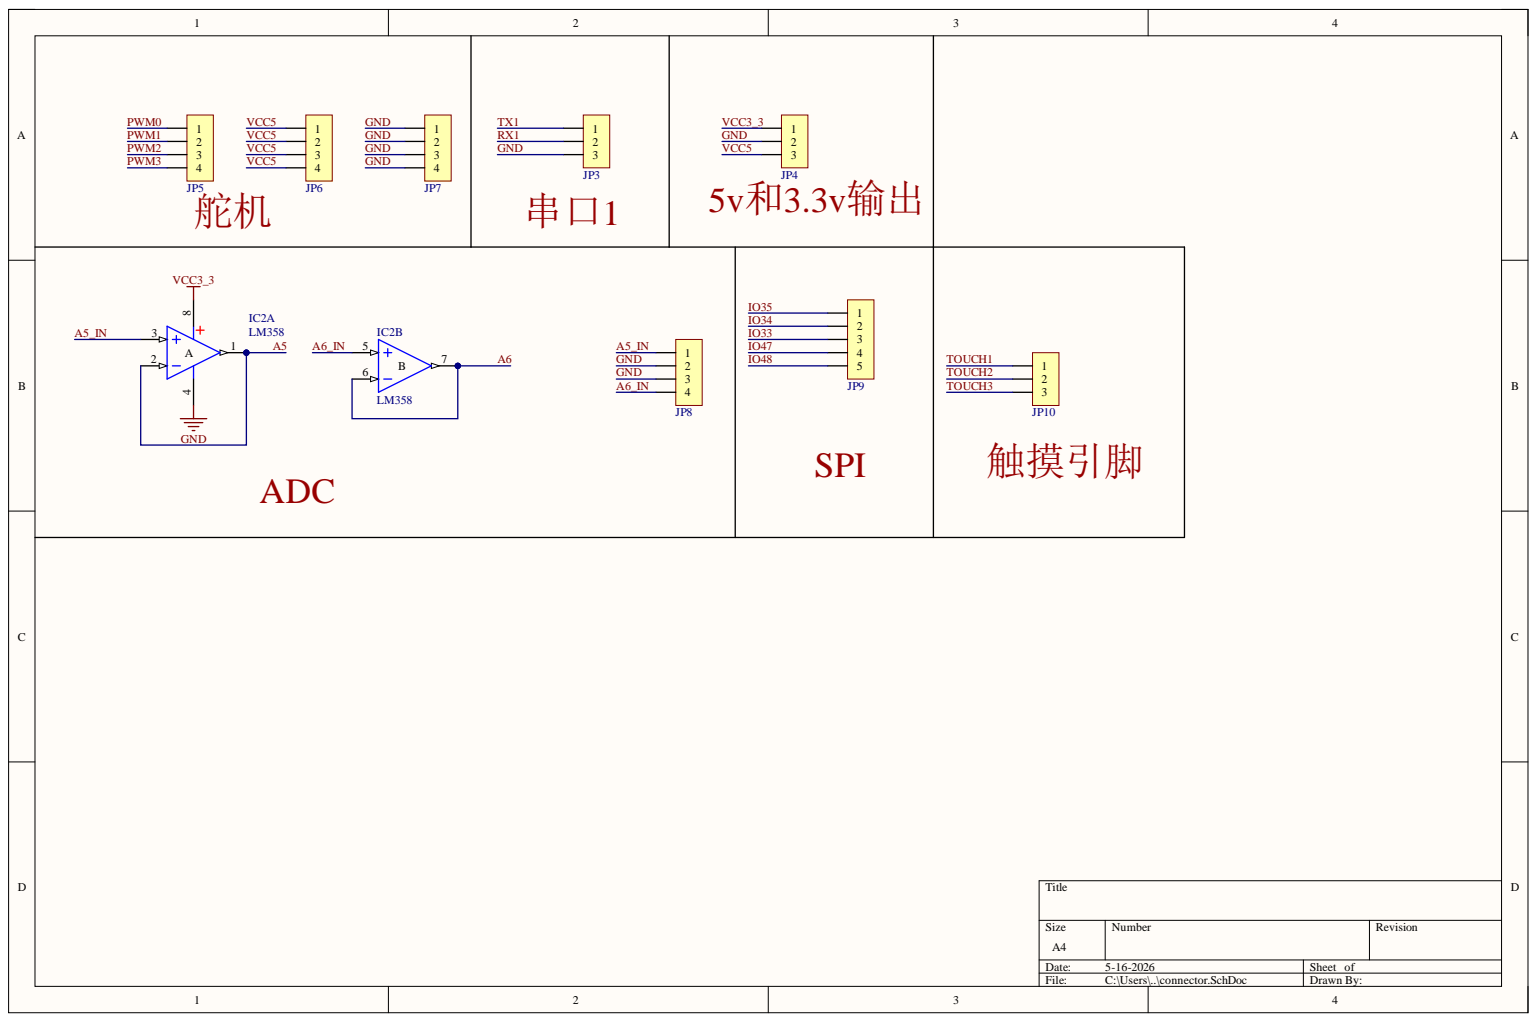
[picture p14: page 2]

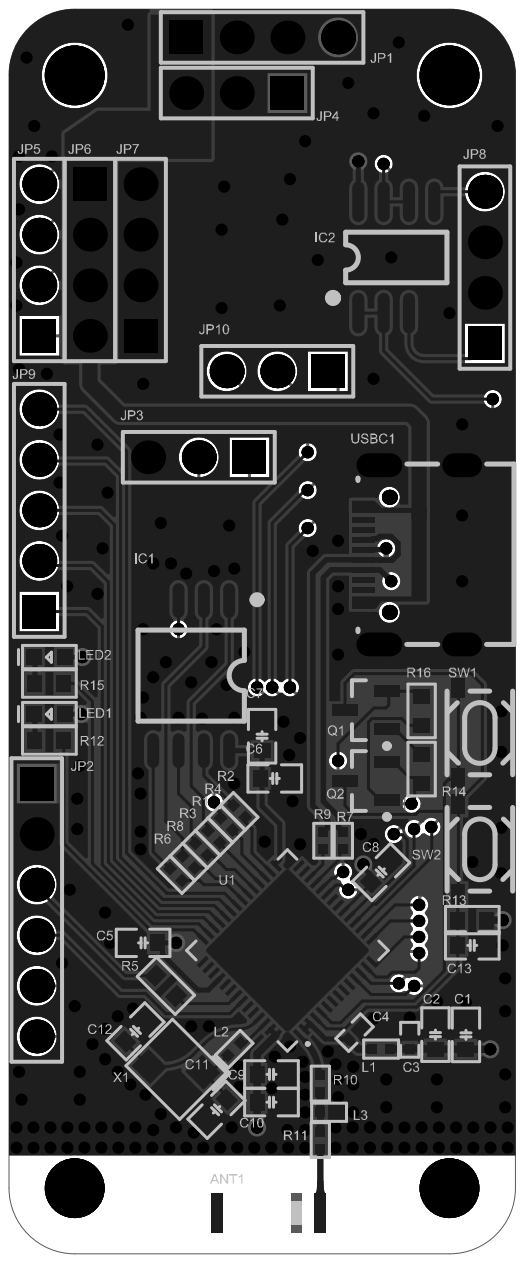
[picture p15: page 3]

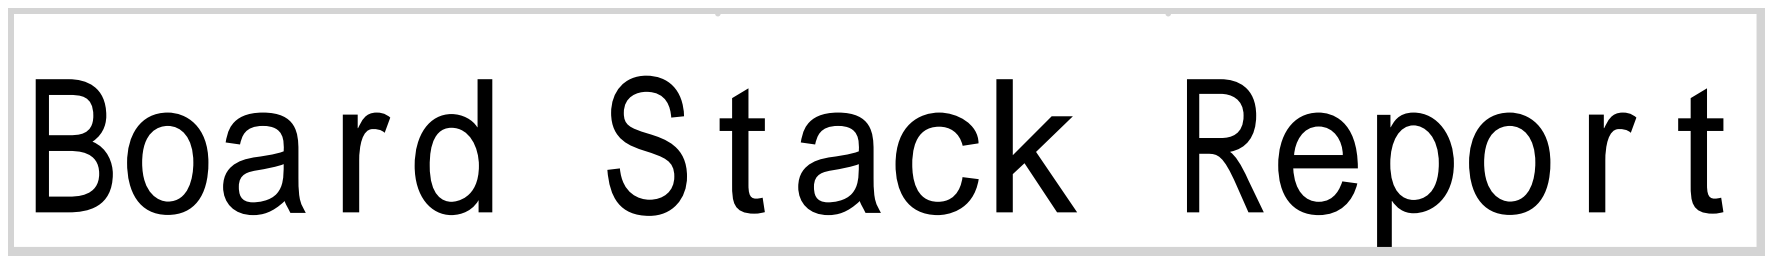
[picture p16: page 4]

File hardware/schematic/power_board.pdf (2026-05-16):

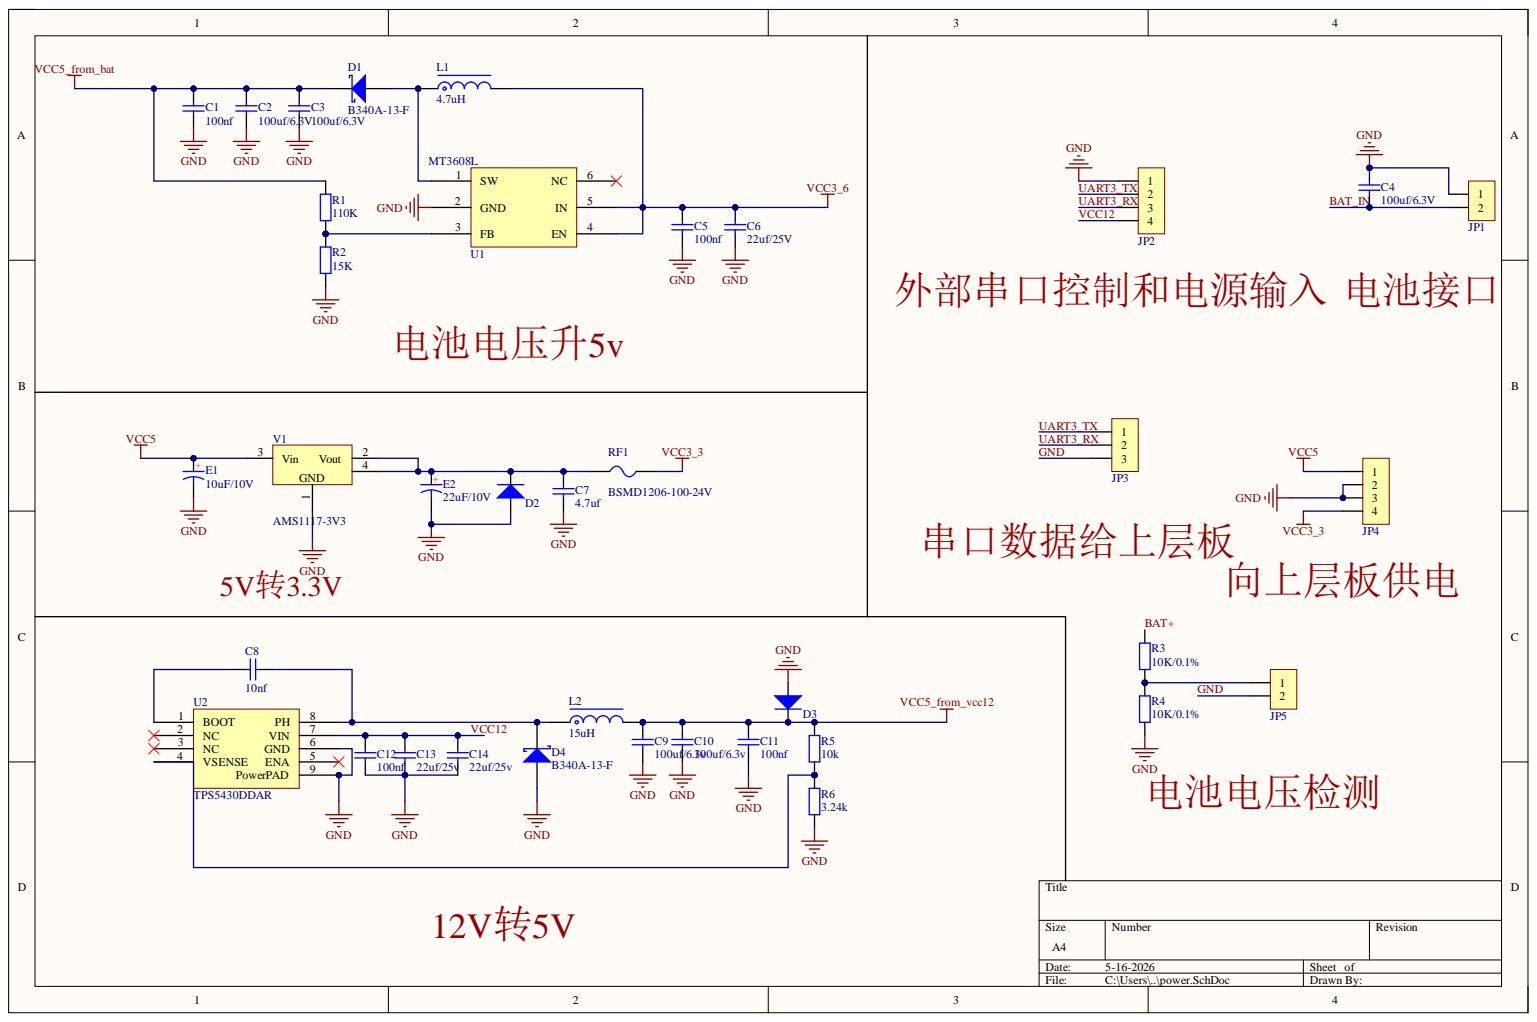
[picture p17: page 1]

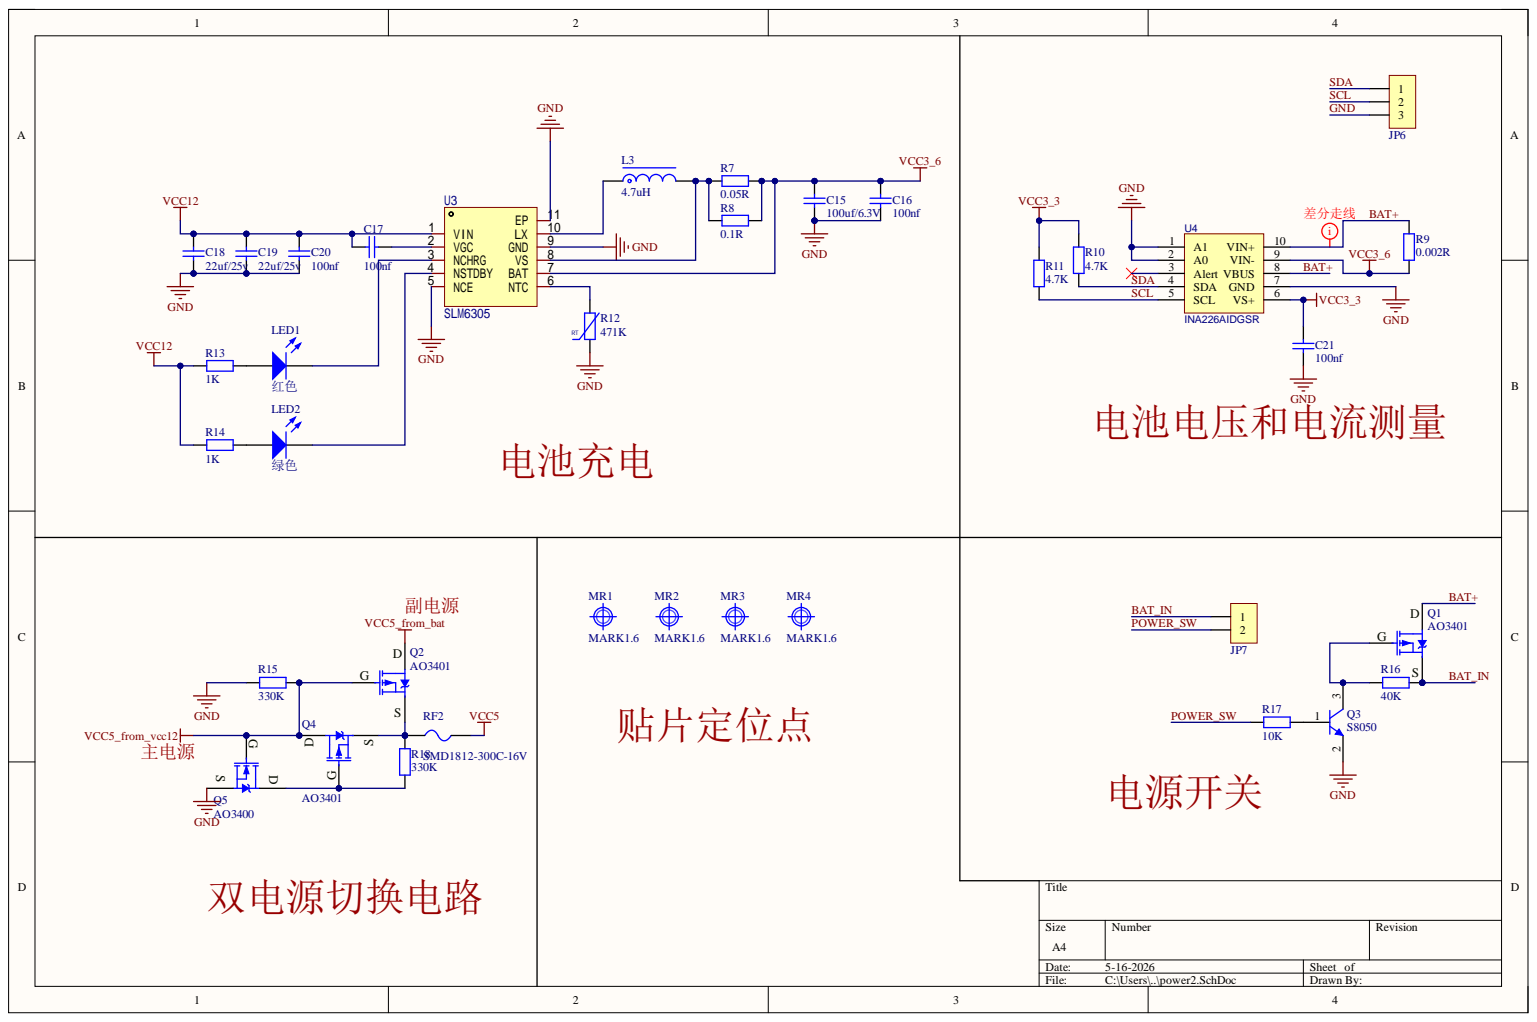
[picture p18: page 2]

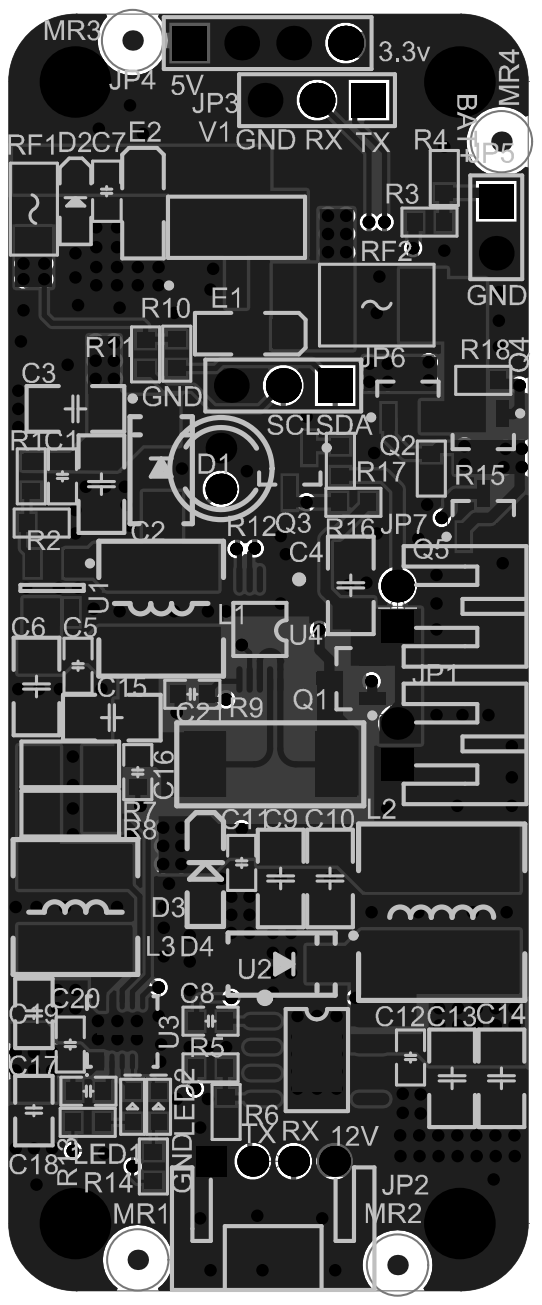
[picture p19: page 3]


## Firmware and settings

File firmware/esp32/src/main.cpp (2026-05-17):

#include <Arduino.h>
#include <ArduinoJson.h>
#include <LittleFS.h>
#include "bsp/BspEpaper.h"
#include "config/AppConfig.h"
#include "service/BatteryService.h"
#include "service/KeyService.h"
#include "service/MqttService.h"
#include "service/WifiService.h"

namespace
{
struct HzkFont
{
  const char *path;
  uint8_t size;
  uint8_t bytesPerRow;
  uint8_t bytesPerGlyph;
};

struct AppState
{
  String messageId;
  String messageText;
  uint32_t messageTs;
  bool hasMessage;
  String lastMessageId;
  String lastCommandId;
  String lastReplyText;
  int batteryPercentage;
  float batteryVoltageV;
  bool batteryReady;
  bool displayDirty;
  String pendingDisplayedId;
};

constexpr HzkFont kHzk16 = {"/fonts/HZK16", 16, 2, 32};
constexpr HzkFont kHzk24 = {"/fonts/HZK24", 24, 3, 72};
constexpr const char *kMapPath = "/fonts/unicode_gb2312.idx";
constexpr uint32_t kInitialWifiAttemptDelayMs = 100;

AppState sState = {};
bool sLittleFsReady = false;
bool sMqttWasConnected = false;
uint32_t sLastWifiAttemptMs = 0;

uint8_t clampBatteryPercentage(float voltage)
{
  if (voltage <= APP_BATTERY_EMPTY_V)
  {
    return 0;
  }
  if (voltage >= APP_BATTERY_FULL_V)
  {
    return 100;
  }

  const float range = APP_BATTERY_FULL_V - APP_BATTERY_EMPTY_V;
  return static_cast<uint8_t>(((voltage - APP_BATTERY_EMPTY_V) * 100.0f / range) + 0.5f);
}

void updateBattery()
{
  if (!BatteryService::begin())
  {
    sState.batteryReady = false;
    sState.batteryPercentage = 0;
    sState.batteryVoltageV = 0.0f;
    return;
  }

  BatteryService::State battery = {};
  if (!BatteryService::getState(battery))
  {
    sState.batteryReady = false;
    sState.batteryPercentage = 0;
    sState.batteryVoltageV = 0.0f;
    return;
  }

  sState.batteryReady = true;
  sState.batteryVoltageV = battery.sample.busVoltageV;
  sState.batteryPercentage = clampBatteryPercentage(battery.sample.busVoltageV);
}

void drawAscii(const char *text, int16_t x, int16_t y, uint8_t size = 1)
{
  BspEpaper::setFont(nullptr);
  BspEpaper::setTextSize(size);
  BspEpaper::setTextColor(GxEPD_BLACK);
  BspEpaper::setCursor(x, y);
  BspEpaper::print(text);
}

void drawMissingGlyph(int16_t x, int16_t y, uint8_t size)
{
  BspEpaper::drawRect(x, y, size, size, GxEPD_BLACK);
  BspEpaper::drawLine(x, y, x + size - 1, y + size - 1, GxEPD_BLACK);
  BspEpaper::drawLine(x, y + size - 1, x + size - 1, y, GxEPD_BLACK);
}

bool readGlyph(const HzkFont &font, uint8_t high, uint8_t low, uint8_t *glyph)
{
  if (high < 0xA1 || low < 0xA1)
  {
    return false;
  }

  const uint32_t area = static_cast<uint32_t>(high - 0xA0);
  const uint32_t position = static_cast<uint32_t>(low - 0xA0);
  if (area == 0 || area > 94 || position == 0 || position > 94)
  {
    return false;
  }

  const uint32_t index = (area - 1) * 94 + (position - 1);
  const uint32_t offset = index * font.bytesPerGlyph;

  File file = LittleFS.open(font.path, "r");
  if (!file)
  {
    return false;
  }

  if (offset + font.bytesPerGlyph > file.size() || !file.seek(offset, SeekSet))
  {
    file.close();
    return false;
  }

  const size_t readBytes = file.read(glyph, font.bytesPerGlyph);
  file.close();
  return readBytes == font.bytesPerGlyph;
}

void drawGlyph(const HzkFont &font, int16_t x, int16_t y, uint8_t high, uint8_t low)
{
  uint8_t glyph[72] = {};
  if (!readGlyph(font, high, low, glyph))
  {
    drawMissingGlyph(x, y, font.size);
    return;
  }

  for (uint8_t row = 0; row < font.size; ++row)
  {
    for (uint8_t byteIndex = 0; byteIndex < font.bytesPerRow; ++byteIndex)
    {
      const uint8_t bits = glyph[row * font.bytesPerRow + byteIndex];
      for (uint8_t bit = 0; bit < 8; ++bit)
      {
        const uint8_t col = byteIndex * 8 + bit;
        if (col < font.size && (bits & (0x80 >> bit)) != 0)
        {
          BspEpaper::drawPixel(x + col, y + row, GxEPD_BLACK);
        }
      }
    }
  }
}

bool lookupGb2312(uint32_t codepoint, uint8_t &high, uint8_t &low)
{
  if (codepoint > 0xFFFF)
  {
    return false;
  }

  File file = LittleFS.open(kMapPath, "r");
  if (!file)
  {
    return false;
  }

  const uint32_t offset = codepoint * 2;
  if (offset + 2 > file.size() || !file.seek(offset, SeekSet))
  {
    file.close();
    return false;
  }

  uint8_t bytes[2] = {};
  const size_t readBytes = file.read(bytes, sizeof(bytes));
  file.close();
  if (readBytes != sizeof(bytes))
  {
    return false;
  }

  const uint16_t gbValue = static_cast<uint16_t>(bytes[0]) |
                           (static_cast<uint16_t>(bytes[1]) << 8);
  if (gbValue == 0)
  {
    return false;
  }

  high = static_cast<uint8_t>(gbValue >> 8);
  low = static_cast<uint8_t>(gbValue & 0xFF);
  return high >= 0xA1 && high <= 0xF7 && low >= 0xA1 && low <= 0xFE;
}

bool decodeNextUtf8(const String &text, size_t &index, uint32_t &codepoint)
{
  if (index >= static_cast<size_t>(text.length()))
  {
    return false;
  }

  const uint8_t first = static_cast<uint8_t>(text[index++]);
  if (first < 0x80)
  {
    codepoint = first;
    return true;
  }

  uint8_t expected = 0;
  uint32_t value = 0;
  if ((first & 0xE0) == 0xC0)
  {
    expected = 1;
    value = first & 0x1F;
  }
  else if ((first & 0xF0) == 0xE0)
  {
    expected = 2;
    value = first & 0x0F;
  }
  else if ((first & 0xF8) == 0xF0)
  {
    expected = 3;
    value = first & 0x07;
  }
  else
  {
    codepoint = '?';
    return true;
  }

  for (uint8_t i = 0; i < expected; ++i)
  {
    if (index >= static_cast<size_t>(text.length()))
    {
      codepoint = '?';
      return true;
    }

    const uint8_t next = static_cast<uint8_t>(text[index++]);
    if ((next & 0xC0) != 0x80)
    {
      codepoint = '?';
      return true;
    }
    value = (value << 6) | (next & 0x3F);
  }

  codepoint = value;
  return true;
}

int16_t drawUtf8Text(const HzkFont &font,
                     const String &text,
                     int16_t x,
                     int16_t y,
                     int16_t maxX,
                     int16_t maxY)
{
  const int16_t startX = x;
  const int16_t lineStep = font.size + 6;
  int16_t cursorX = x;
  int16_t cursorY = y;
  size_t index = 0;

  while (index < static_cast<size_t>(text.length()) && cursorY + font.size <= maxY)
  {
    uint32_t codepoint = 0;
    if (!decodeNextUtf8(text, index, codepoint))
    {
      break;
    }

    if (codepoint == '\n')
    {
      cursorX = startX;
      cursorY += lineStep;
      continue;
    }

    const bool ascii = codepoint >= 0x20 && codepoint <= 0x7E;
    const int16_t charWidth = ascii ? 7 : font.size + 2;
    if (cursorX + charWidth > maxX)
    {
      cursorX = startX;
      cursorY += lineStep;
      if (cursorY + font.size > maxY)
      {
        break;
      }
    }

    if (ascii)
    {
      char asciiText[2] = {static_cast<char>(codepoint), '\0'};
      drawAscii(asciiText, cursorX, cursorY + max<int16_t>((font.size - 8) / 2, 0));
    }
    else
    {
      uint8_t high = 0;
      uint8_t low = 0;
      if (lookupGb2312(codepoint, high, low))
      {
        drawGlyph(font, cursorX, cursorY, high, low);
      }
      else
      {
        drawMissingGlyph(cursorX, cursorY, font.size);
      }
    }

    cursorX += charWidth;
  }

  return cursorY + font.size;
}

void drawBatteryIcon(int16_t x, int16_t y, int percentage)
{
  BspEpaper::drawRect(x, y, 24, 12, GxEPD_BLACK);
  BspEpaper::fillRect(x + 24, y + 4, 3, 4, GxEPD_BLACK);
  const int fillW = constrain((percentage * 20) / 100, 0, 20);
  if (fillW > 0)
  {
    BspEpaper::fillRect(x + 2, y + 2, fillW, 8, GxEPD_BLACK);
  }
}

void drawStatusBar()
{
  const int16_t w = BspEpaper::width();
  BspEpaper::drawFastHLine(6, 23, w - 12, GxEPD_BLACK);
  drawAscii("INK 001", 8, 8);
  drawAscii(MqttService::isConnected() ? "MQTT" : "OFF", 66, 8);

  char info[32] = {};
  snprintf(info, sizeof(info), "RSSI %ld", static_cast<long>(WifiService::rssi()));
  drawAscii(info, 112, 8);

  drawBatteryIcon(w - 38, 6, sState.batteryPercentage);
}

void drawReplyHints()
{
  const int16_t y = BspEpaper::height() - 20;
  BspEpaper::drawFastHLine(6, y - 7, BspEpaper::width() - 12, GxEPD_BLACK);
  drawUtf8Text(kHzk16, "左短 已收到  右短 待确认", 10, y, BspEpaper::width() - 8, BspEpaper::height() - 2);
}

void drawMessagePage()
{
  const int16_t w = BspEpaper::width();
  const int16_t h = BspEpaper::height();
  BspEpaper::fillScreen(GxEPD_WHITE);
  drawStatusBar();

  if (sState.hasMessage)
  {
    drawUtf8Text(kHzk24, sState.messageText, 12, 36, w - 10, h - 54);

    if (sState.lastReplyText.length() > 0)
    {
      String reply = "已回复：";
      reply += sState.lastReplyText;
      drawUtf8Text(kHzk16, reply, 12, h - 44, w - 10, h - 26);
    }
  }
  else
  {
    drawUtf8Text(kHzk24, "等待留言", 74, 58, w - 10, h - 48);
  }

  drawReplyHints();
}

bool renderDisplay()
{
  Serial.println("[display] refresh");
  BspEpaper::begin();
  BspEpaper::setRotation(APP_DISPLAY_ROTATION);
  BspEpaper::setFullWindow();
  BspEpaper::firstPage();
  do
  {
    if (!sLittleFsReady)
    {
      BspEpaper::fillScreen(GxEPD_WHITE);
      drawAscii("LittleFS mount failed", 10, 40);
      drawAscii("Upload filesystem.", 10, 58);
    }
    else
    {
      drawMessagePage();
    }
  } while (BspEpaper::nextPage());
  BspEpaper::powerOff();
  Serial.println("[display] done");
  return true;
}

bool publishJsonDocument(const JsonDocument &doc, bool retain = false)
{
  char payload[512] = {};
  const size_t length = serializeJson(doc, payload, sizeof(payload));
  if (length == 0 || length >= sizeof(payload))
  {
    Serial.println("[mqtt] serialize failed");
    return false;
  }
  return MqttService::publishJson(APP_MQTT_TOPIC_STATUS_TO_PHONE, payload, retain);
}

void publishOnlineStatus()
{
  updateBattery();

  JsonDocument doc;
  doc["online"] = true;
  doc["battery"] = sState.batteryReady ? sState.batteryPercentage : 0;
  doc["rssi"] = WifiService::rssi();
  doc["fw"] = APP_FIRMWARE_VERSION;
  publishJsonDocument(doc, true);
}

void publishMessageState(const String &msgId, const char *state)
{
  if (msgId.length() == 0)
  {
    return;
  }

  JsonDocument doc;
  doc["msg_id"] = msgId;
  doc["state"] = state;
  publishJsonDocument(doc, false);
}

void publishReply(const char *state, const char *text)
{
  if (!sState.hasMessage)
  {
    Serial.println("[key] ignored, no active message");
    return;
  }

  JsonDocument doc;
  doc["msg_id"] = sState.messageId;
  doc["state"] = state;
  doc["text"] = text;
  publishJsonDocument(doc, false);

  sState.lastReplyText = text;
  sState.displayDirty = true;
}

String payloadToString(const uint8_t *payload, unsigned int length)
{
  String text;
  text.reserve(length + 1);
  for (unsigned int i = 0; i < length; ++i)
  {
    text += static_cast<char>(payload[i]);
  }
  return text;
}

void handleIncomingMessage(const uint8_t *payload, unsigned int length)
{
  const String body = payloadToString(payload, length);
  JsonDocument doc;
  DeserializationError error = deserializeJson(doc, body);
  if (error)
  {
    Serial.print("[msg] json error: ");
    Serial.println(error.c_str());
    return;
  }

  const char *id = doc["id"] | "";
  const char *type = doc["type"] | "";
  const char *text = doc["text"] | "";
  const uint32_t ts = doc["ts"] | 0;

  if (id[0] == '\0' || text[0] == '\0')
  {
    Serial.println("[msg] missing id/text");
    return;
  }

  if (sState.lastMessageId == id)
  {
    Serial.print("[msg] duplicate ignored id=");
    Serial.println(id);
    return;
  }

  sState.messageId = id;
  sState.lastMessageId = id;
  sState.messageText = text;
  sState.messageTs = ts;
  sState.hasMessage = true;
  sState.lastReplyText = "";
  sState.displayDirty = true;
  sState.pendingDisplayedId = id;

  Serial.print("[msg] accepted id=");
  Serial.print(id);
  Serial.print(" type=");
  Serial.println(type);
  publishMessageState(sState.messageId, "accepted");
}

void handleIncomingCommand(const uint8_t *payload, unsigned int length)
{
  const String body = payloadToString(payload, length);
  JsonDocument doc;
  DeserializationError error = deserializeJson(doc, body);
  if (error)
  {
    Serial.print("[cmd] json error: ");
    Serial.println(error.c_str());
    return;
  }

  const char *id = doc["id"] | "";
  const char *cmd = doc["cmd"] | "";
  if (id[0] == '\0' || cmd[0] == '\0')
  {
    Serial.println("[cmd] missing id/cmd");
    return;
  }

  if (sState.lastCommandId == id)
  {
    Serial.print("[cmd] duplicate ignored id=");
    Serial.println(id);
    return;
  }
  sState.lastCommandId = id;

  if (strcmp(cmd, "refresh") == 0)
  {
    sState.displayDirty = true;
    Serial.println("[cmd] refresh");
  }
  else if (strcmp(cmd, "clear") == 0)
  {
    sState.messageId = "";
    sState.messageText = "";
    sState.pendingDisplayedId = "";
    sState.hasMessage = false;
    sState.lastReplyText = "";
    sState.displayDirty = true;
    Serial.println("[cmd] clear");
  }
}

void handleMqttMessage(const char *topic, const uint8_t *payload, unsigned int length)
{
  if (strcmp(topic, APP_MQTT_TOPIC_MSG_TO_ESP32) == 0)
  {
    handleIncomingMessage(payload, length);
  }
  else if (strcmp(topic, APP_MQTT_TOPIC_CMD_TO_ESP32) == 0)
  {
    handleIncomingCommand(payload, length);
  }
}

void maintainWifi()
{
  if (WifiService::isConnected())
  {
    return;
  }

  const uint32_t nowMs = millis();
  if (sLastWifiAttemptMs != 0 &&
      nowMs - sLastWifiAttemptMs < APP_WIFI_RETRY_INTERVAL_MS)
  {
    return;
  }

  sLastWifiAttemptMs = nowMs == 0 ? kInitialWifiAttemptDelayMs : nowMs;
  WifiService::begin();
}

void maintainMqtt()
{
  if (!WifiService::isConnected())
  {
    sMqttWasConnected = false;
    return;
  }

  MqttService::loop();
  const bool connected = MqttService::isConnected();
  if (connected && !sMqttWasConnected)
  {
    Serial.println("[mqtt] online event");
    publishOnlineStatus();
    sState.displayDirty = true;
  }
  sMqttWasConnected = connected;
}

void handleKeyEvent(const KeyService::KeyEvent &event)
{
  if (event.key == KeyService::KeyId::Left && event.action == KeyService::KeyAction::ShortPress)
  {
    publishReply("seen", "已收到");
  }
  else if (event.key == KeyService::KeyId::Right && event.action == KeyService::KeyAction::ShortPress)
  {
    publishReply("confirm", "需要确认");
  }
  else if (event.key == KeyService::KeyId::Left && event.action == KeyService::KeyAction::LongPress)
  {
    publishReply("later", "稍后处理");
  }
  else if (event.key == KeyService::KeyId::Right && event.action == KeyService::KeyAction::LongPress)
  {
    publishReply("done", "已处理");
  }
}

void processKeys()
{
  KeyService::KeyEvent event = {};
  while (KeyService::getEvent(event, 0))
  {
    handleKeyEvent(event);
  }
}

void processDisplay()
{
  if (!sState.displayDirty)
  {
    return;
  }

  sState.displayDirty = false;
  const String displayedId = sState.pendingDisplayedId;
  const bool rendered = renderDisplay();
  if (rendered && displayedId.length() > 0)
  {
    publishMessageState(displayedId, "displayed");
    sState.pendingDisplayedId = "";
  }
}
}

void setup()
{
  Serial.begin(115200);
  delay(500);
  Serial.println();
  Serial.println("ink mqtt terminal");

  sLittleFsReady = LittleFS.begin(false);
  Serial.print("[fs] LittleFS=");
  Serial.println(sLittleFsReady ? "ok" : "fail");

  updateBattery();
  KeyService::begin();
  MqttService::setMessageHandler(handleMqttMessage);

  sState.displayDirty = true;
  processDisplay();
}

void loop()
{
  maintainWifi();
  maintainMqtt();
  processKeys();
  processDisplay();
  delay(10);
}

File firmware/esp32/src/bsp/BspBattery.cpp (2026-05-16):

#include "BspBattery.h"

#include <Wire.h>
#include "INA226.h"

#define BSP_BATTERY_REG_SHUNT_VOLTAGE 0x01
#define BSP_BATTERY_REG_BUS_VOLTAGE 0x02
#define BSP_BATTERY_REG_POWER 0x03
#define BSP_BATTERY_REG_CURRENT 0x04
#define BSP_BATTERY_REG_MANUFACTURER 0xFE
#define BSP_BATTERY_REG_DIE_ID 0xFF

namespace BspBattery
{
namespace
{
INA226 sIna226(BSP_BATTERY_I2C_ADDRESS, &Wire);
bool sReady = false;

bool readRegister(uint8_t reg, uint16_t &value)
{
  Wire.beginTransmission(BSP_BATTERY_I2C_ADDRESS);
  Wire.write(reg);
  if (Wire.endTransmission() != 0)
  {
    return false;
  }

  const uint8_t bytesRead = Wire.requestFrom(
      static_cast<uint8_t>(BSP_BATTERY_I2C_ADDRESS),
      static_cast<uint8_t>(2));
  if (bytesRead != 2)
  {
    while (Wire.available() > 0)
    {
      Wire.read();
    }
    return false;
  }

  value = static_cast<uint16_t>(Wire.read()) << 8;
  value |= static_cast<uint16_t>(Wire.read());
  return true;
}
}

bool begin()
{
  Wire.end();
  pinMode(BSP_BATTERY_SDA_PIN, INPUT_PULLUP);
  pinMode(BSP_BATTERY_SCL_PIN, INPUT_PULLUP);

  if (!Wire.begin(BSP_BATTERY_SDA_PIN, BSP_BATTERY_SCL_PIN, BSP_BATTERY_I2C_SPEED_HZ))
  {
    Serial.println("I2C begin failed");
    sReady = false;
    return false;
  }
  Wire.setTimeOut(50);
  delay(10);

  if (!sIna226.begin())
  {
    Serial.println("INA226 not connected");
    sReady = false;
    return false;
  }

  uint16_t manufacturer = 0;
  uint16_t die = 0;
  if (readRegister(BSP_BATTERY_REG_MANUFACTURER, manufacturer) &&
      readRegister(BSP_BATTERY_REG_DIE_ID, die))
  {
    Serial.print("INA226 manufacturer=0x");
    Serial.print(manufacturer, HEX);
    Serial.print(" die=0x");
    Serial.println(die, HEX);
  }

  const int calibrationError = sIna226.setMaxCurrentShunt(BSP_BATTERY_MAX_CURRENT_A, BSP_BATTERY_SHUNT_OHM);
  if (calibrationError != INA226_ERR_NONE)
  {
    Serial.print("INA226 calibration error=0x");
    Serial.println(calibrationError, HEX);
    sReady = false;
    return false;
  }

  Serial.print("INA226 max current=");
  Serial.print(sIna226.getMaxCurrent(), 3);
  Serial.print("A shunt=");
  Serial.print(sIna226.getShunt(), 4);
  Serial.print("R current_lsb=");
  Serial.print(sIna226.getCurrentLSB_mA(), 6);
  Serial.println("mA");

  sReady = true;
  return true;
}

bool isReady()
{
  return sReady;
}

bool readRaw(RawSample &sample)
{
  if (!sReady && !begin())
  {
    return false;
  }

  if (!readRegister(BSP_BATTERY_REG_SHUNT_VOLTAGE, sample.shuntVoltage) ||
      !readRegister(BSP_BATTERY_REG_BUS_VOLTAGE, sample.busVoltage) ||
      !readRegister(BSP_BATTERY_REG_POWER, sample.power) ||
      !readRegister(BSP_BATTERY_REG_CURRENT, sample.current))
  {
    Serial.println("INA226 read failed");
    sReady = false;
    return false;
  }

  return true;
}

bool read(Sample &sample)
{
  RawSample raw = {};
  if (!readRaw(raw))
  {
    return false;
  }

  sample.raw = raw;
  sample.busVoltageV = raw.busVoltage * 1.25e-3f;
  sample.shuntVoltageMv = static_cast<int16_t>(raw.shuntVoltage) * 2.5e-3f;
  sample.currentA = static_cast<int16_t>(raw.current) * sIna226.getCurrentLSB();
  sample.powerW = raw.power * sIna226.getCurrentLSB() * 25.0f;
  sample.timestampMs = millis();
  return true;
}

float currentLsbA()
{
  return sIna226.getCurrentLSB();
}
}

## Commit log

2026-05-16 Initial open-source prototype
    [connector.SchDoc, esp32-s3.SchDoc, esp32-s3_poly.PcbDoc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]
2026-05-16 Clarify MIT hardware license and add flow diagrams
2026-05-17 Add project and PCB image galleries
